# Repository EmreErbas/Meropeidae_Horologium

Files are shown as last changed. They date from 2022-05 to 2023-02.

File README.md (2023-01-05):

# Meropeidae Horologium

---
>**This project contains sub-modules. Clone the project recursively**
>
>`git clone --recurse-submodules git@github.com:EmreErbas/Meropeidae_Horologium.git`

---

## Meropeidae Horologium

It is a computer, consisting of a 16x36 resolution screen inspired by [Nixie Tubes](https://en.wikipedia.org/wiki/Nixie_tube), made of single-color LEDs selected according to the wavelength of the light emitted in the excitation of neon gas, and a WiFi-connected controller that drives it.

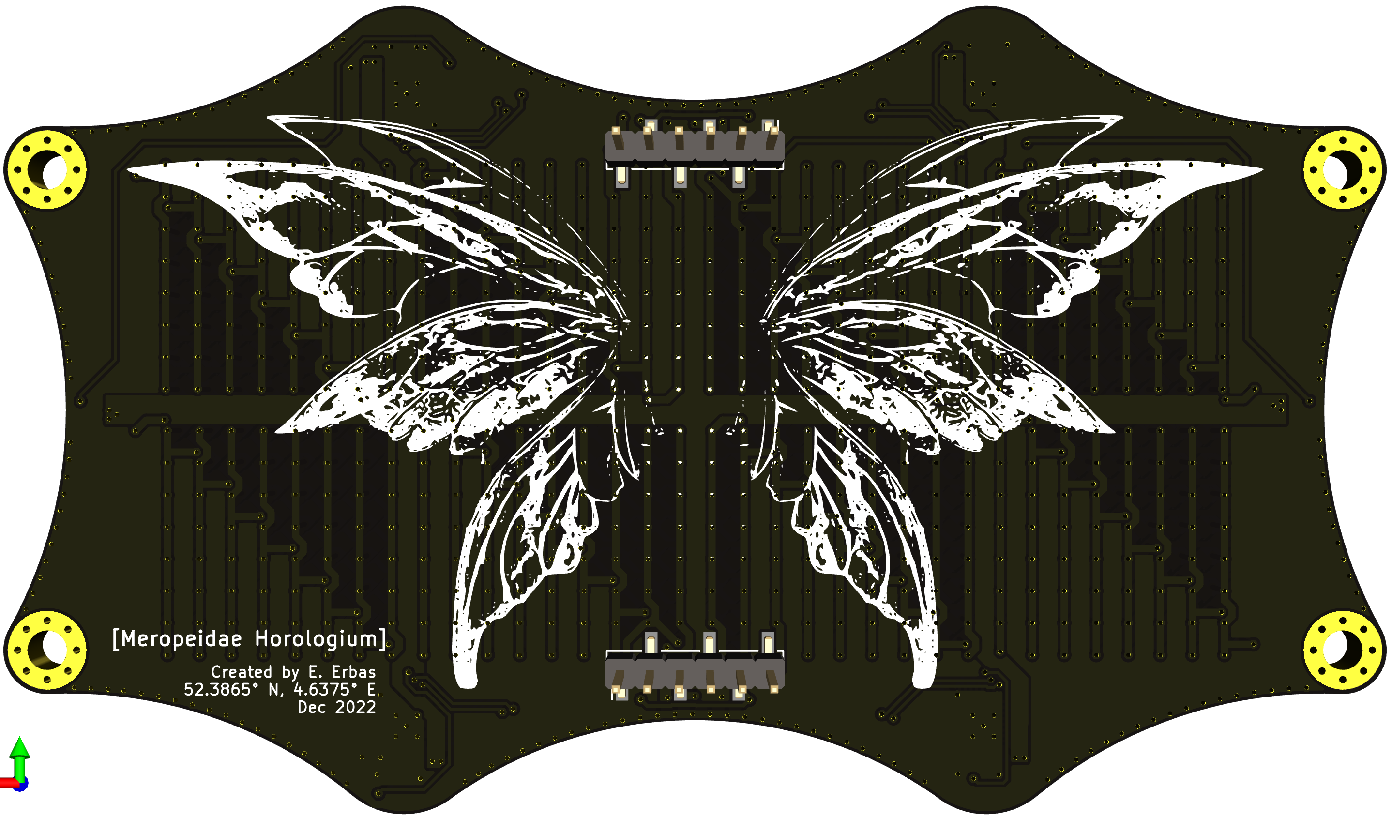
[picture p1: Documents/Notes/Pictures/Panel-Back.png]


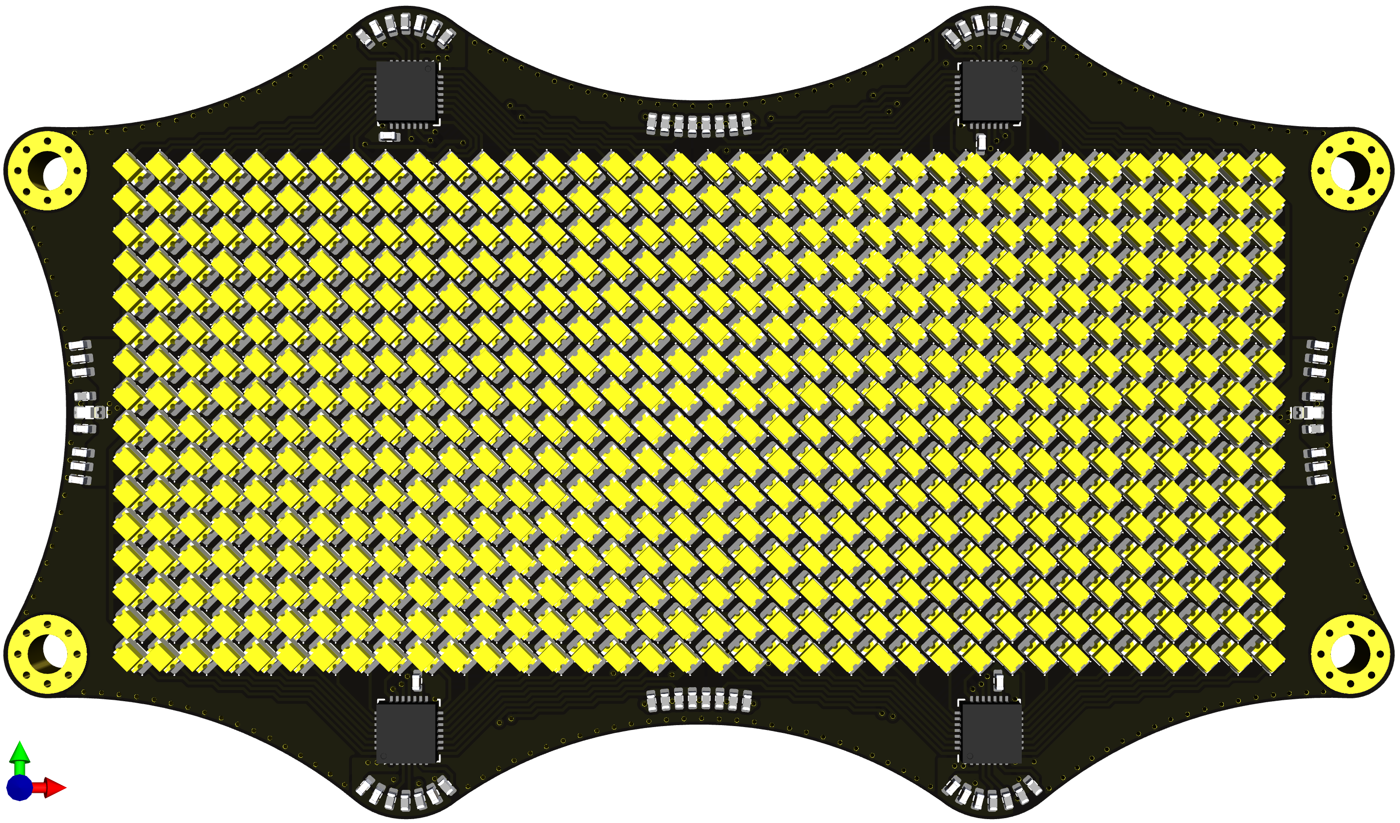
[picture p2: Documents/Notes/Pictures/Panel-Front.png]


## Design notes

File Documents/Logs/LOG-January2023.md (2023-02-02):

# Nixie-LOG-January2023 //legacy log

<pre>

<b>01-Jun-2023</b>  Started to write documents about the project

<b>02-Jun-2023</b>  Started to take technical notes. Created a file system

<b>12-Jun-2023</b>  NixiePanel PCB is arrived. ESP32-S3-Mini is arrived

<b>15-Jun-2023</b>  ESP32-S3-Mini is not really easy to use :/ I think there are some missing and/or buggy codes on the
             bootloader feature in the current library. Although I could download some simple codes, I cannot 
             download them again without entering the factory-boot-mode

<b>16-Jun-2023</b>  I saw the first light today. The PCB is working like a charm. I didn't have to change anything on the 
             hardware. But probably using two individual I2C will be a bit painful. Maybe it is wise to convert 
             the circuit for a single bus.
             Also, I need to focus on the speed of communication. I am sending all the pixels from the beginning 
             to change a single pixel. Speed is quite essential in that case. But of course, I need to find another 
             way to scan the screen.
             
<b>24-Jun-2023</b>  Every function on the panel works perfectly. Gamma correction was clearly needed and I applied it. 
             It looks like we can get very successful results somewhere between 1.6-2.0.
             I only have one issue with the system. Unfortunately, it's running extremely slow, processes with I2C. 
             Strangely, it doesn't look like it's directly connected. So I'm not entirely sure what is the source 
             of this delay. Now is the time to focus on that.
                           
<b>29-Jun-2023</b>  Interpolation and gamma correction is working like a charm. Its feeling is very flawless. First, I 
            have used more pixel data to create more smooth flow but it could not create this feeling. Then I tried 
            another method and created virtual pixels. Now, pixel positions are not integer but float. And with a 
            simgle weight calculation equation, I change the neigbor pixels' data. And it works!

</pre>

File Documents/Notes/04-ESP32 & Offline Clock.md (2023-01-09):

# ESP32 & Offline Clock

## HTML basics

`<!DOCTYPE HTML><html>` indicates that we are sending HTML  
`<head><meta name="viewport" content="width=device-width, initial-scale=1">` makes the web page responsive in any web browser
`<link rel="icon" href="data:,">` prevent requests on the favicon  
`<style>html { font-family: Helvetica; display: inline-block; margin: 0px auto; text-align: center;}` some CSS text to style the buttons and the web page appearance  
`.button { background-color: #4CAF50; border: none; color: white; padding: 16px 40px; text-decoration: none; font-size: 30px; margin: 2px; cursor: pointer;}`  
`.button2 {background-color: #555555;}</style></head>`

```html
<!DOCTYPE html>  
<html>  
<head>  
  <meta name="viewport" content="width=device-width, initial-scale=1">  
  <link rel="icon" href="data:,">  
  <style>html { font-family: Helvetica; display: inline-block; margin: 0px auto; text-align: center;}  
    .button { background-color: #4CAF50; border: none; color: white; padding: 16px 40px; 
      text-decoration: none; font-size: 30px; margin: 2px; cursor: pointer;}  
    .button2 {background-color: #555555; border: none; color: white; padding: 16px 40px; 
      text-decoration: none; font-size: 30px; margin: 2px; cursor: pointer;}  
  </style>  
  <p>  
    <a href="/26/on"><button class="button">ON</button></a>  
    <a href="/27/off"><button class="button2">OFF</button></a>  
  </p>  
</head>  
<body>  
  <h1>My First Heading</h1>  
  <p>My first paragraph.</p>  
</body>  
</html>  
```

This [webpage](https://randomnerdtutorials.com/esp32-web-server-arduino-ide/) can be useful for quick start.

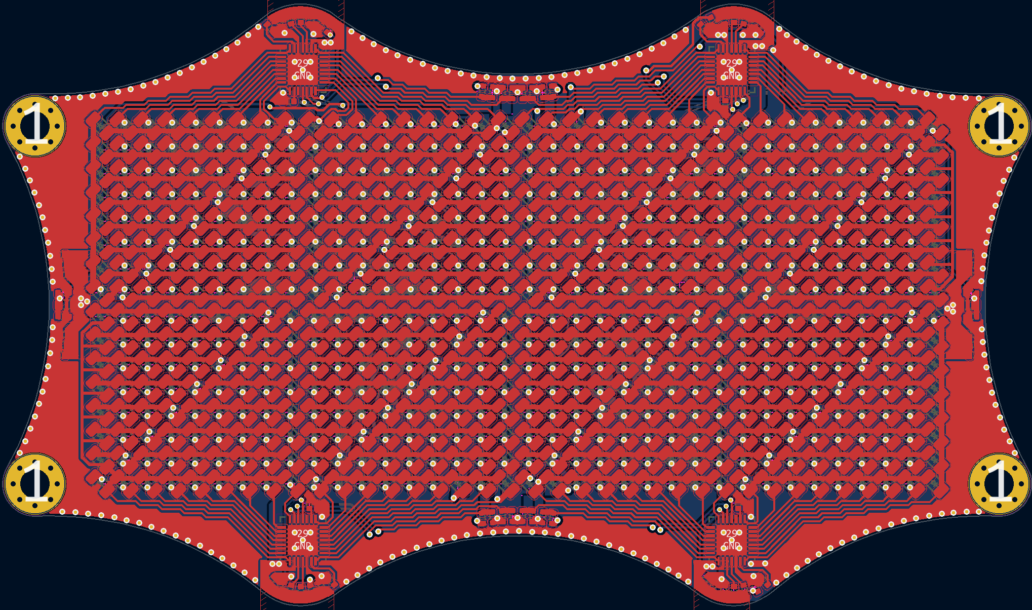
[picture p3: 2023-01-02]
Documents/Notes/Pictures/Panel-Overview.png

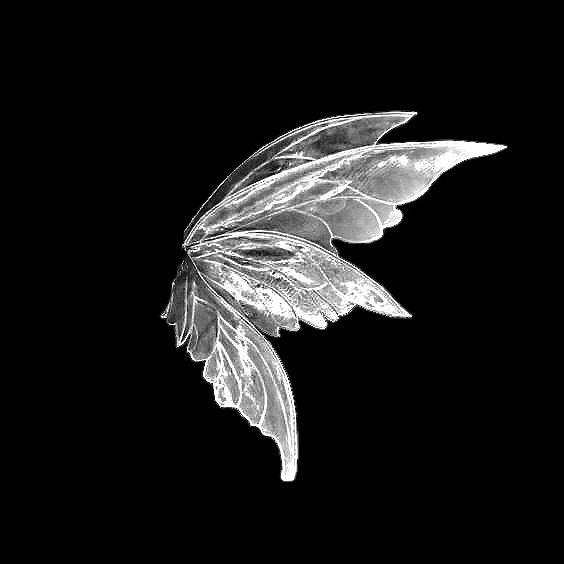
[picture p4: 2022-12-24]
Circuit Design/nixie-panel/FF75309D-6EDD-47AD-B004-FEA218AC76D5_1_201_a.jpeg

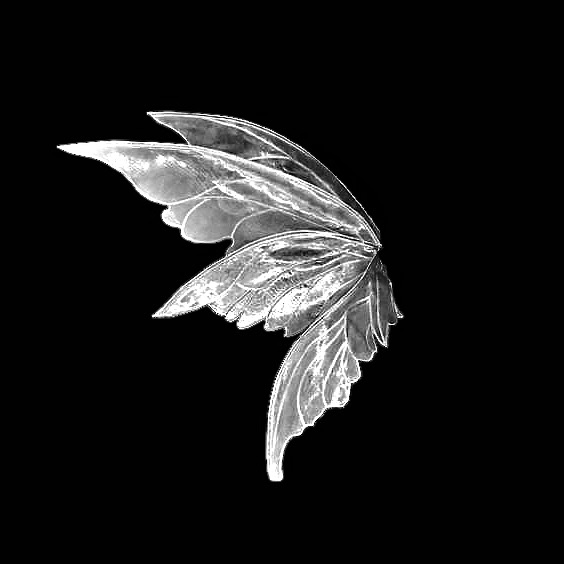
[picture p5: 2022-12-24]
Circuit Design/nixie-panel/FF75309D-6EDD-47AD-B004-FEA218AC76D5_1_201_a 2.jpeg

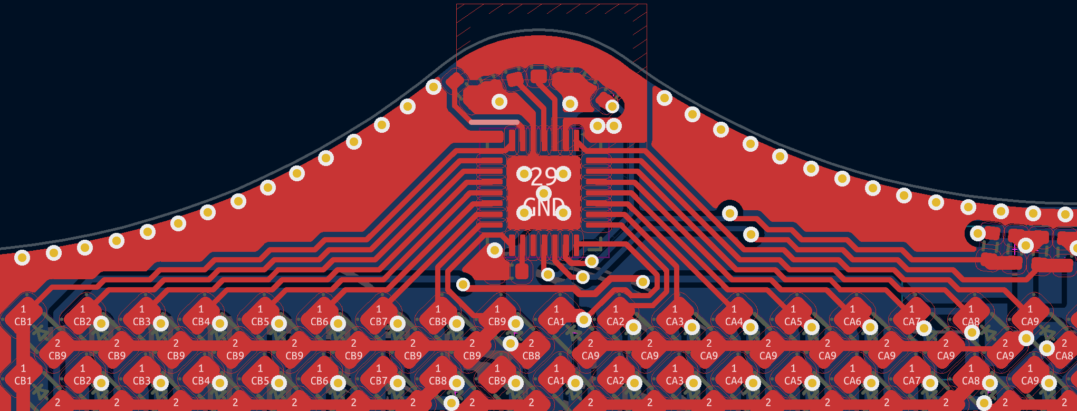
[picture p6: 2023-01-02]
Documents/Notes/Pictures/LED Driver.png

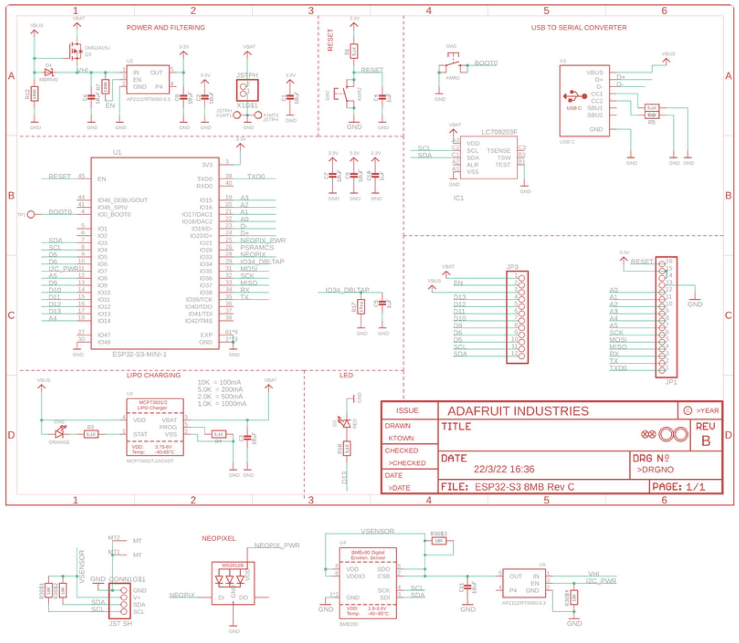
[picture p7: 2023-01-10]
Documents/Notes/Pictures/ESP32-S3-Feather-Sch.png

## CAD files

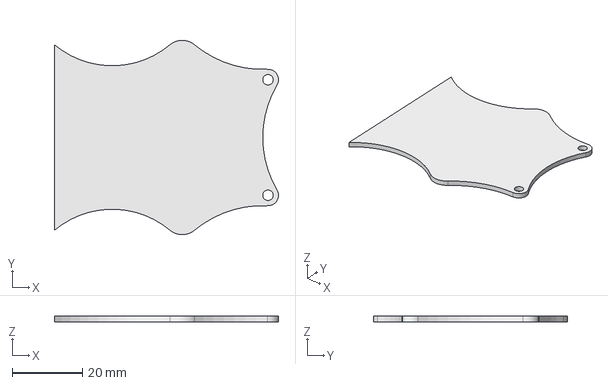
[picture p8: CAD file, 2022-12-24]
Circuit Design/nixie-panel/nixiePanelShape/nixiePanelShape.FCStd
64.0 x 55.5 x 1.60 mm

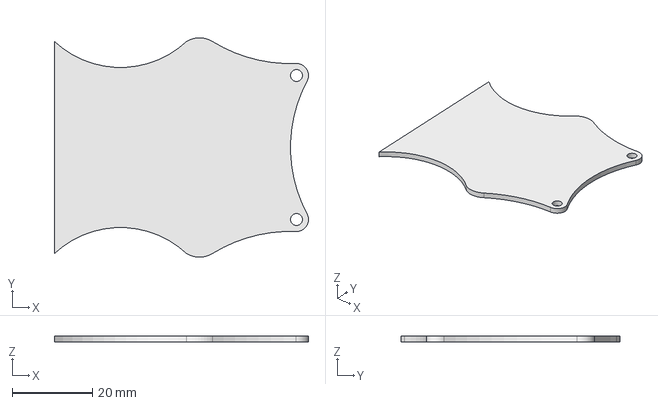
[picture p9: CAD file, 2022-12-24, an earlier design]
Circuit Design/nixie-panel/nixiePanelShape/backup/nixiePanelShape.FCStd
63.5 x 54.8 x 1.60 mm

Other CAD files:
Circuit Design/nixie-panel/nixiePanelShape/backup/nixiePanelShape.dxf
Circuit Design/nixie-panel/nixiePanelShape/nixiePanelShape.dxf

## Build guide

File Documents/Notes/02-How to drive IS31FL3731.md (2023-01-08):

# How to Drive IS31FL3731
## IS31FL3731
### GENERAL DESCRIPTION

The [IS31FL3731](https://www.lumissil.com/assets/pdf/core/IS31FL3731_DS.pdf) is a compact LED driver for 144 single LEDs. The device can be programmed via an I2C compatible interface. The IS31FL3731 offers two blocks each driving 72 LEDs with 1/9 cycle rate. The required lines to drive all 144 LEDs are reduced to 18 by using the cross-plexing feature optimizing space on the PCB. Additionally each of the 144 LEDs can be dimmed individually with 8-bit allowing 256 steps of linear dimming.

To reduce CPU usage up to 8 frames can be stored with individual time delays between frames to play small animations automatically. LED frames can be modulated with audio signal.

IS31FL3731 is available in QFN-28 (4mm × 4mm) and SSOP-28 package. It operates from 2.7V to 5.5V over the temperature range of -40°C to +85°C.

### FEATURES
* Supply voltage range: 2.7V to 5.5V 
* 400kHz I2C-compatible interface
* 144 LEDs in dot matrix
* Individual blink control
* 8 frames memory for animations
* Picture mode and animation mode
* Auto intensity breathing during the switching of different frames
* LED frames displayed can be modulated with audio signal intensity
* LED light intensity can be modulated with audio signal intensity
* QFN-28 (4mm × 4mm) and SSOP-28 package

Typical Application Circuit is:
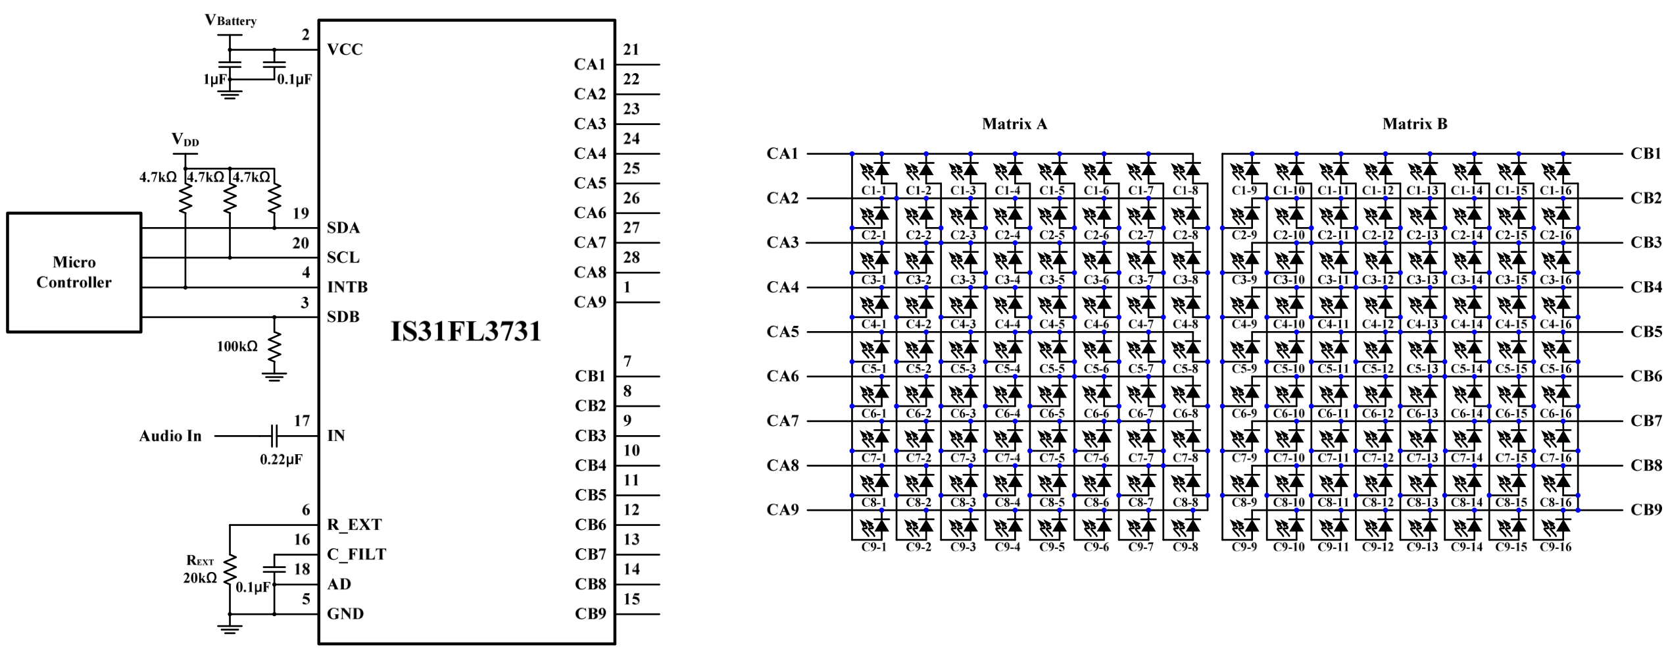
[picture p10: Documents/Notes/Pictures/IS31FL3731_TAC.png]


The circuit that the Nixie-Panel project uses is: 
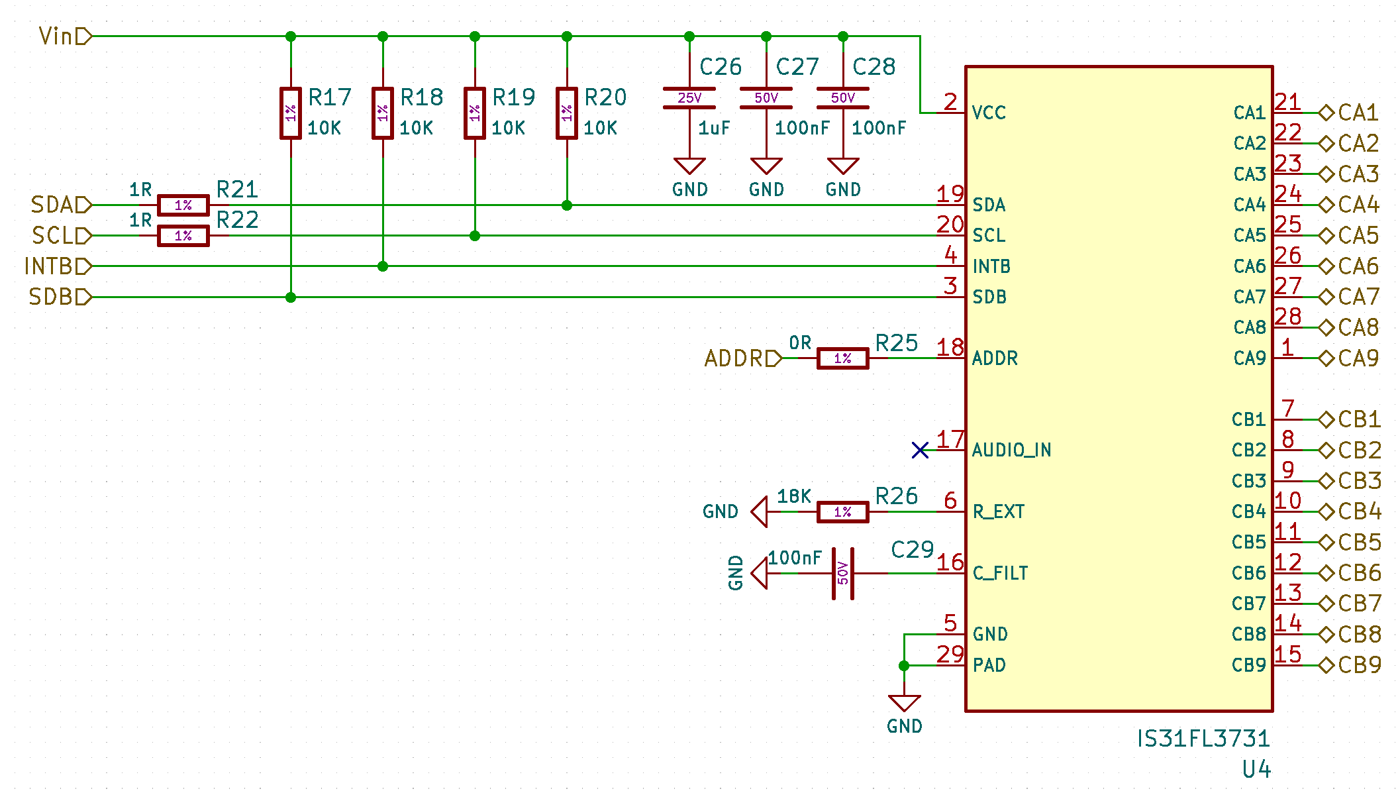
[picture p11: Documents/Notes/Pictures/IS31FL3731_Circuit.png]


under this hierarchical page:
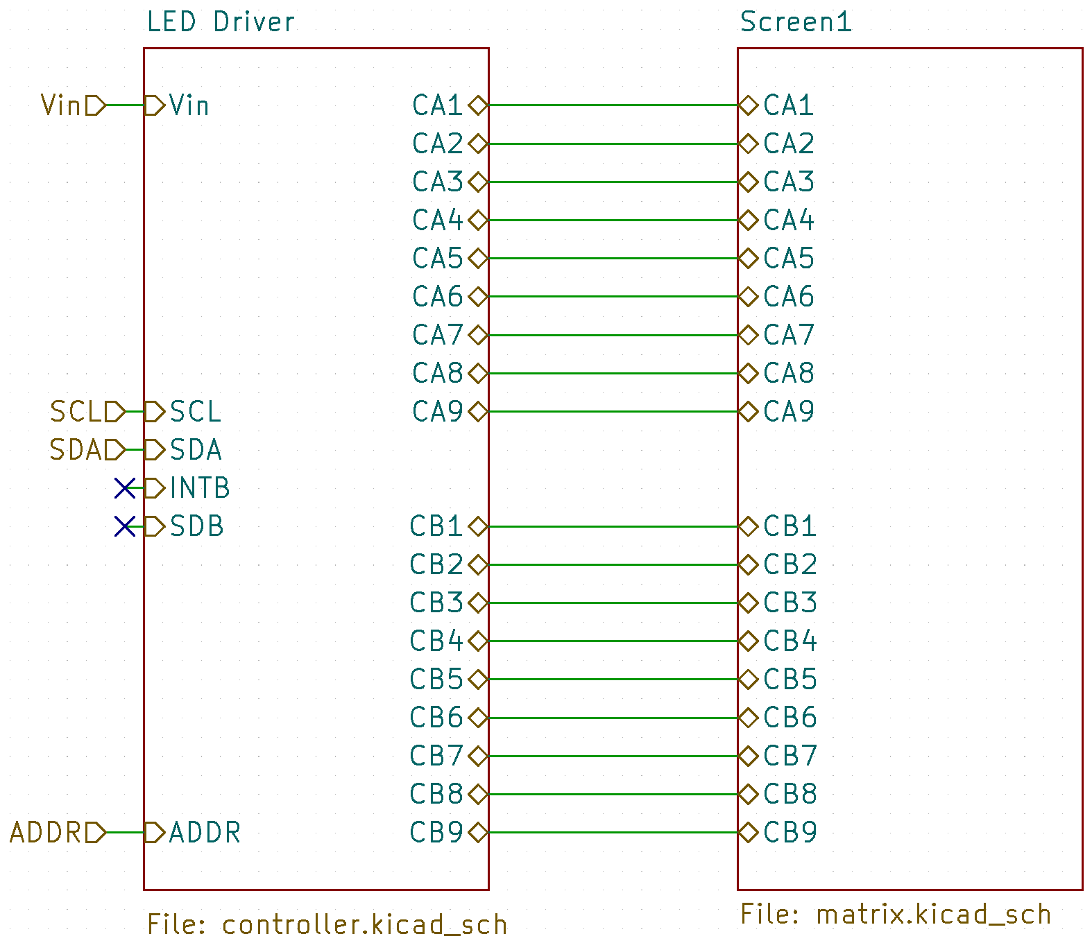
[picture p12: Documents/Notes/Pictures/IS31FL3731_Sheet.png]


## Driving the IC
Adafruit has a library for this IC. [Here](https://learn.adafruit.com/i31fl3731-16x9-charliplexed-pwm-led-driver/overview) is the link.

Open up the Arduino library manager:  
Search for the `Adafruit IS31FL3731` library and install it  
Search for the `Adafruit GFX` library and install it  

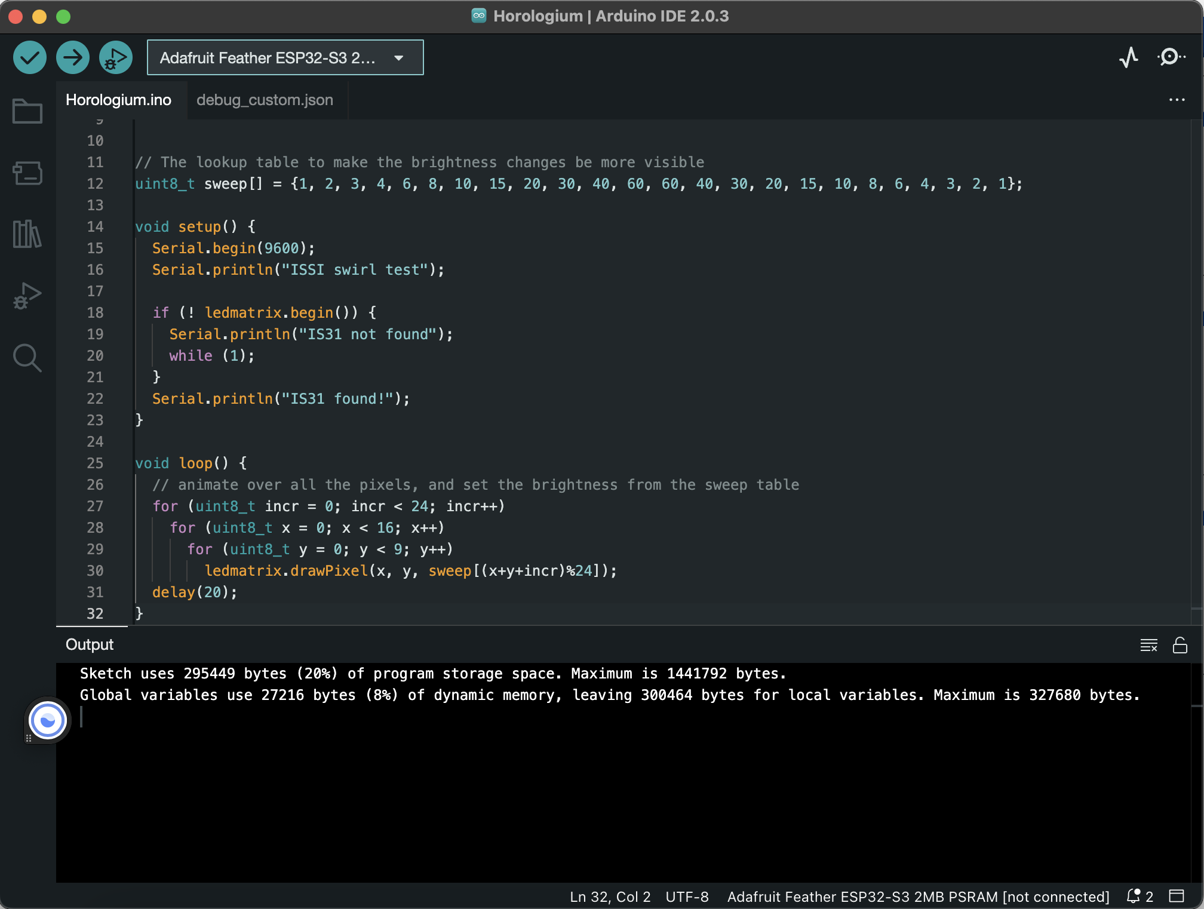
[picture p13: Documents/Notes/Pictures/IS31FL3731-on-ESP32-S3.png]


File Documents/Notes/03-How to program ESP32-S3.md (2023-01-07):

# How to Program ESP32-S3
## ESP32-S3 
<dl>
<dt>2.4 GHz WiFi + Bluetooth-LE SoC</dt>
<dt>Supporting IEEE 802.11b/g/n (2.4 GHz WiFi) and Bluetooth ® 5 (LE)</dt>
</dl>

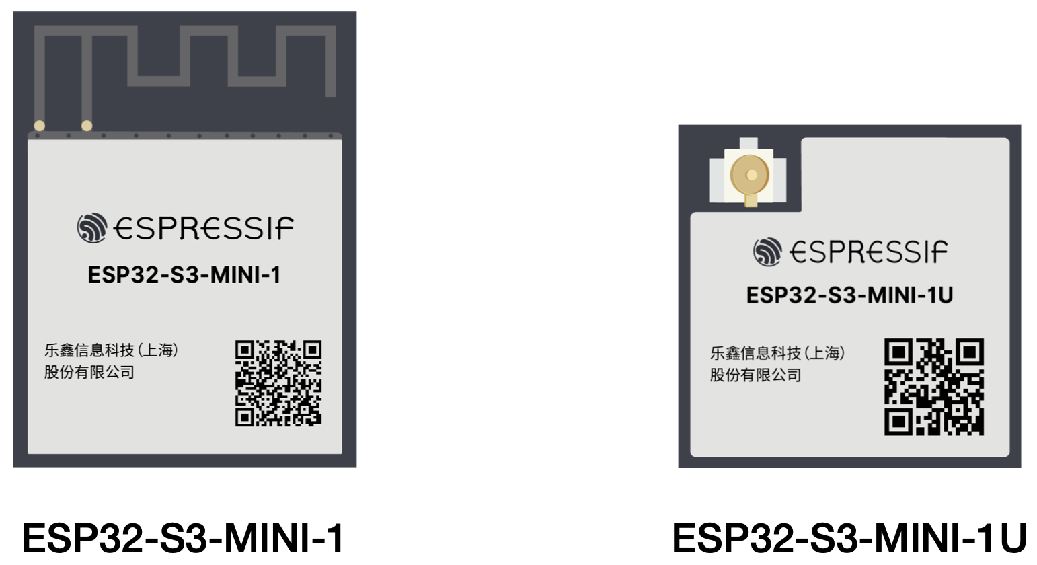
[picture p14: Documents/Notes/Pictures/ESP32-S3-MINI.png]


[ESP32-S3](https://cdn-shop.adafruit.com/product-files/5477/esp32-s3_datasheet_en.pdf) is a low-power MCU-based system-on-chip (SoC) that supports 2.4 GHz Wi-Fi and Bluetooth® Low Energy (Bluetooth LE). It consists of high-performance dual-core microprocessor (Xtensa® 32-bit LX7), a lowpower coprocessor, a Wi-Fi baseband, a Bluetooth LE baseband, RF module, and peripherals.

### FEATURES
#### WiFi
* IEEE 802.11 b/g/n-compliant
* Supports 20 MHz, 40 MHz bandwidth in 2.4 GHz band
* 1T1R mode with data rate up to 150 Mbps
* Wi-Fi Multimedia (WMM)
* TX/RX A-MPDU, TX/RX A-MSDU
* Immediate Block ACK
* Fragmentation and defragmentation
* Automatic Beacon monitoring (hardware TSF)
* 4 × virtual Wi-Fi interfaces
* Simultaneous support for Infrastructure BSS in Station, SoftAP, or Station + SoftAP modes Note that when ESP32-S3 scans in Station mode, the SoftAP channel will change along with the Station channel
* Antenna diversity
* 802.11mc FTM
* External PA is supported 
#### Bluetooth
* Bluetooth LE: Bluetooth 5, Bluetooth mesh
* High power mode (20 dBm, share the same PA with Wi-Fi)
* Speed: 125 Kbps, 500 Kbps, 1 Mbps, 2 Mbps
* Advertising extensions
* Multiple advertisement sets
* Channel selection algorithm #2
* Internal co-existence mechanism between Wi-Fi and Bluetooth to share the same antenna 
#### CPU and Memory
* Xtensa® dual-core 32-bit LX7 microprocessor, up to 240 MHz
* CoreMark® 
    score:
    - 1 core at 240 MHz: 613.86 CoreMark; 2.56 CoreMark/MHz    
    - 2 cores at 240 MHz: 1181.60 CoreMark; 4.92 CoreMark/MHz
* 128-bit data bus and SIMD commands
* 384 KB ROM
* 512 KB SRAM
* 16 KB SRAM in RTC
* SPI, Dual SPI, Quad SPI, Octal SPI, QPI and OPI interfaces that allow connection to multiple flash and external RAM
* Flash controller with cache is supported
* Flash in-Circuit Programming (ICP) is supported
#### Advanced Peripheral Interfaces
* 45 × programmable GPIOs
* Digital 
    interfaces:
    - 4 × SPI
    - 1 × LCD interface (8-bit ~16-bit parallel RGB, I8080 and MOTO6800), 
        - supporting conversion between RGB565, YUV422, YUV420 and YUV411
    - 1 × DVP 8-bit ~16-bit camera interface
    - 3 × UART
    - 2 × I2C
    - 2 × I2S
    - 1 × RMT (TX/RX)
    - 1 × pulse counter
    - LED PWM controller, up to 8 channels
    - 1 × full-speed USB OTG
    - 1 × USB Serial/JTAG controller
    - 2 × MCPWM
    - 1 × SDIO host controller with 2 slots
    - General DMA controller (GDMA), with 5 transmit channels and 5 receive channels
    - 1 × TWAI® controller, compatible with ISO 11898-1 (CAN Specification 2.0)
* Analog 
    interfaces:
    - 2 × 12-bit SAR ADCs, up to 20 channels
    - 1 × temperature sensor
    - 14 × touch sensing IOs
* Timers
    :
    - 4 × 54-bit general-purpose timers
    - 1 × 52-bit system timer
    - 3 × watchdog timers
Low Power Management
* Power Management Unit with five power modes
* Ultra-Low-Power (ULP) 
    coprocessors:
    - ULP-RISC-V coprocessor
    - ULP-FSM coprocessor
Security
* Secure boot
* Flash encryption
* 4-Kbit OTP, up to 1792 bits for users
* Cryptographic hardware 
    acceleration:
    - AES-128/256 (FIPS PUB 197)
    - Hash (FIPS PUB 180-4)
    - RSA
    - Random Number Generator (RNG)
    - HMAC
    - Digital signature

### DEVELOPMENT BOARDS

#### [Adafruit ESP32-S3 Feather](https://learn.adafruit.com/adafruit-esp32-s3-feather)


##### Features:
* ESP32-S3 Dual Core 240MHz Tensilica processor the next generation of ESP32-Sx, with native USB so it can act like a keyboard/mouse, MIDI device, disk drive, etc!
* Mini module has FCC/CE certification and comes with either 8 MByte of Flash, no PSRAM or 4MByte of Flash, and 2MB PSRAM (depending on the Feather you purchased)
* Power options - USB type C or Lipoly battery
* Built-in battery charging when powered over USB-C
* LiPoly battery monitor - LC709203 chip actively monitors your battery for voltage and state of charge / percentage reporting over I2C
* Reset and DFU (BOOT0) buttons to get into the ROM bootloader (which is a USB serial port so you don't need a separate cable!)
* Serial debug output pin (optional, for checking the hardware serial debug console)
* STEMMA QT connector for I2C devices, with switchable power, so you can go into low power mode.
* On/Charge/User LEDs + status NeoPixel with pin-controlled power for low power usage
* Low Power friendly! In deep sleep mode we can get down to ~100uA of current draw from the Lipoly connection. Quiescent current is from the power regulator, ESP32-S3 chip, and Lipoly monitor. Turn off the NeoPixel and external I2C power for the lowest quiescent current draw.

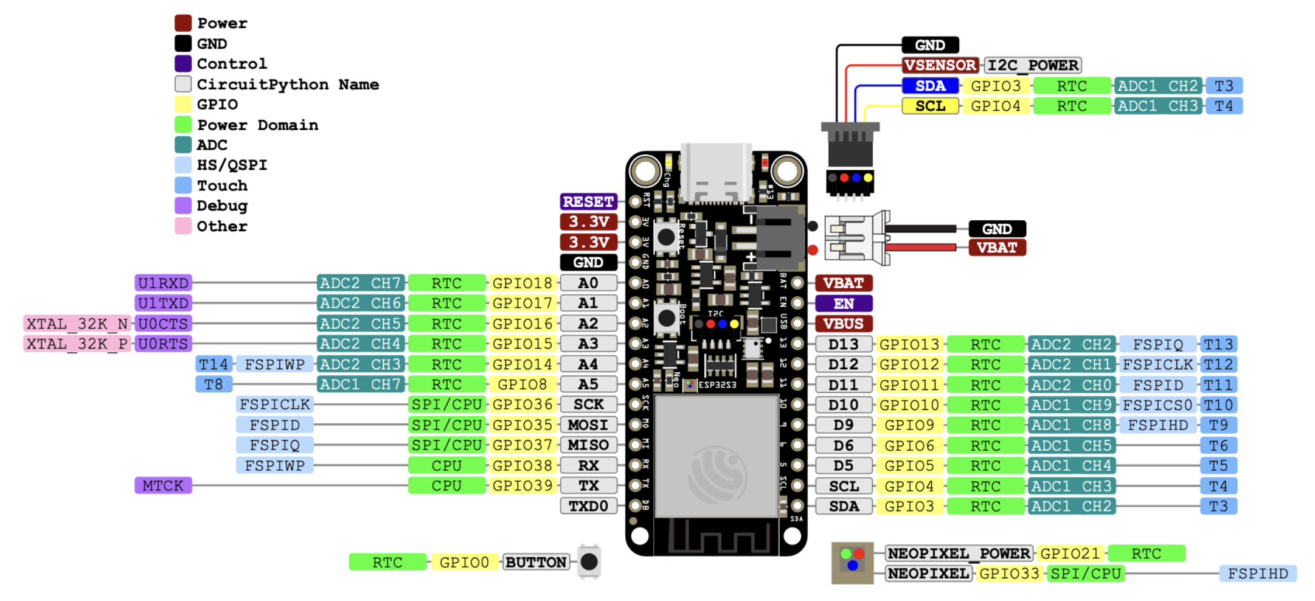
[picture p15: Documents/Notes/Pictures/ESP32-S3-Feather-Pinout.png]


### How to install the libraries

Check the [Guide](https://docs.espressif.com/projects/arduino-esp32/en/latest/installing.html#macos).

For macOS, you must istall `git` and `git-gui`.
Detailed guide is [here](https://git-scm.com/download/mac).

**[The repository of the library](https://github.com/espressif/arduino-esp32.git)**

Obviously, we need to have git installed on our PC, always.  
`$ brew install git`

The official guide recommends git-gui for installation. To follow the official guide, you need to solve several issues. I do not prefer to use the gui tool which is quite buggy on macOS. But still, you can find the solutions below.

> `$ brew install git-gui`  
> Then, you can run the gui `$ git-gui`
> 
> if python 3.9 is missing, then  
> `$ xcode-select --install`
> 
> Choose **Clone Existing Repository**  
> The source location is `https://github.com/espressif/arduino-esp32.git`  
> The target directory is `[ARDUINO_SKETCHBOOK_DIR]/hardware/espressif/esp32`, usually `/Users/[user_name]/Documents/Arduino/hardware/espressif/esp32`
> 
> **Important note:** git-gui malfunction: can not create a directory or clone one  
> to solve it, use `$ git config --global init.defaultBranch main`

Or, just run this command on terminal:  
`$ git clone --recurse-submodules https://github.com/espressif/arduino-esp32.git`

Download (get) ESP32 Board files, tools etc.  
`$ cd esp32/tools`  
`$ python3 get.py` (`python` or `python3` depends on your machine)

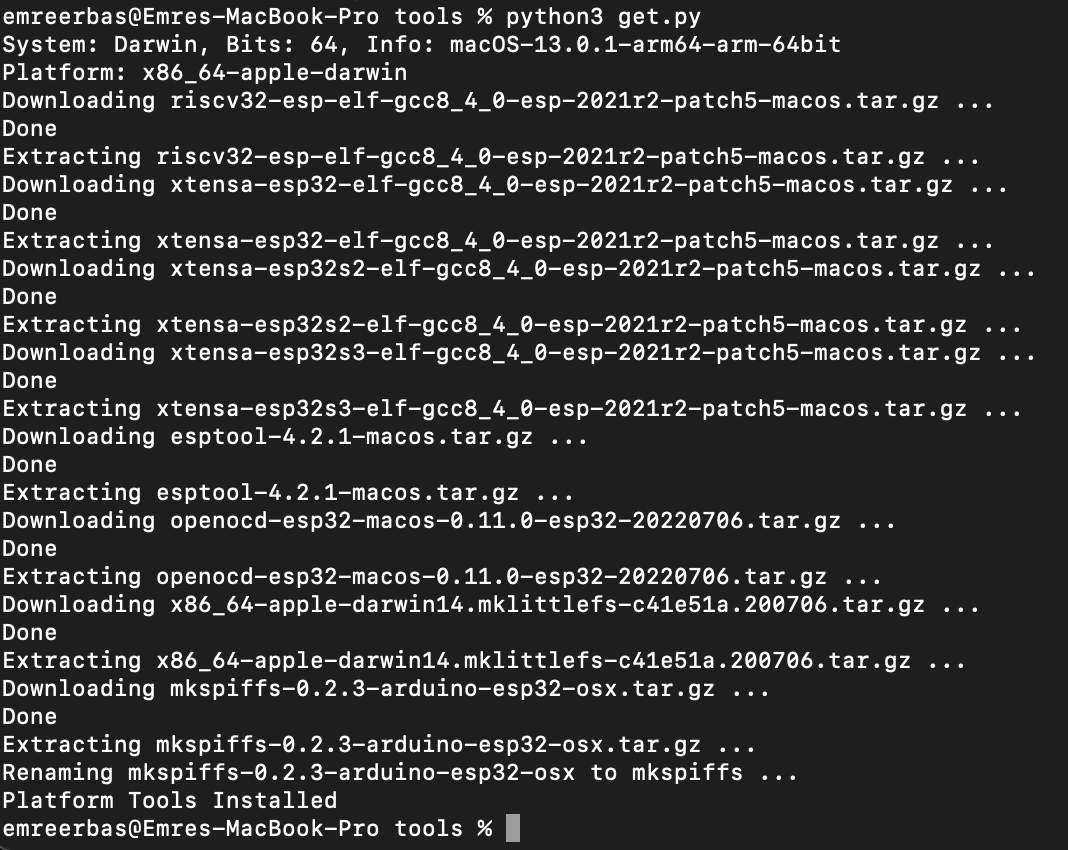
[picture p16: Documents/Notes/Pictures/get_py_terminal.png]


That is it!  
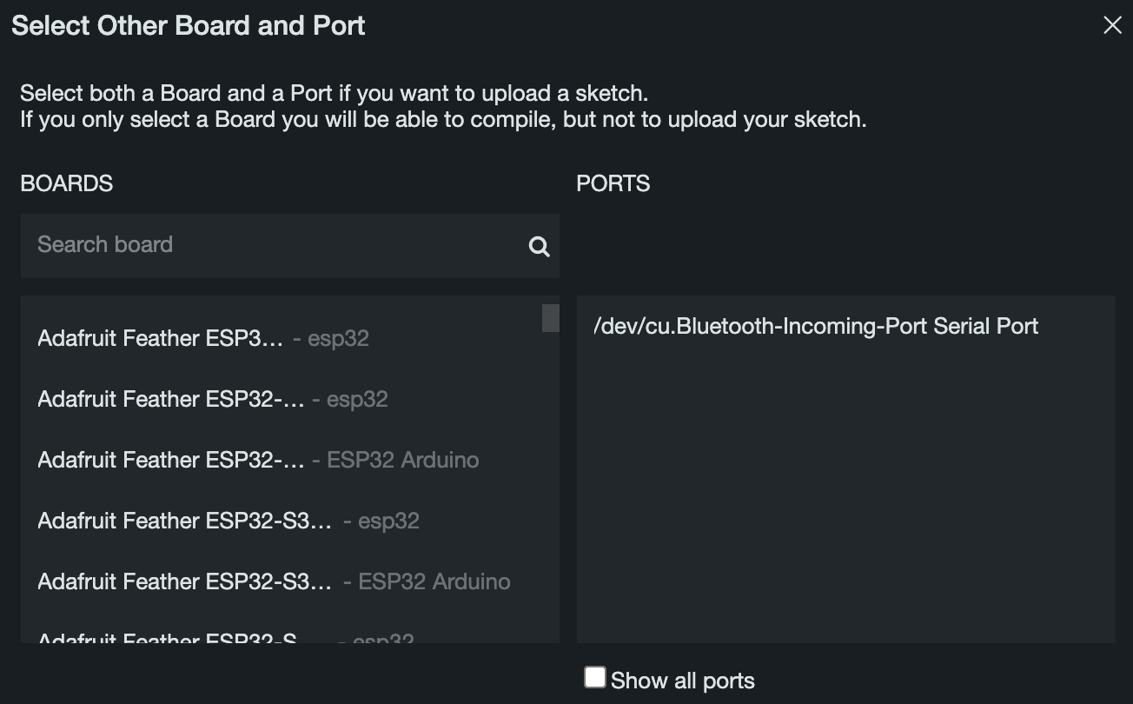
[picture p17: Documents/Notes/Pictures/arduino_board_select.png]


### Arduino IDE
Check the [Guide](https://learn.adafruit.com/adafruit-esp32-s3-feather/arduino-ide-setup)

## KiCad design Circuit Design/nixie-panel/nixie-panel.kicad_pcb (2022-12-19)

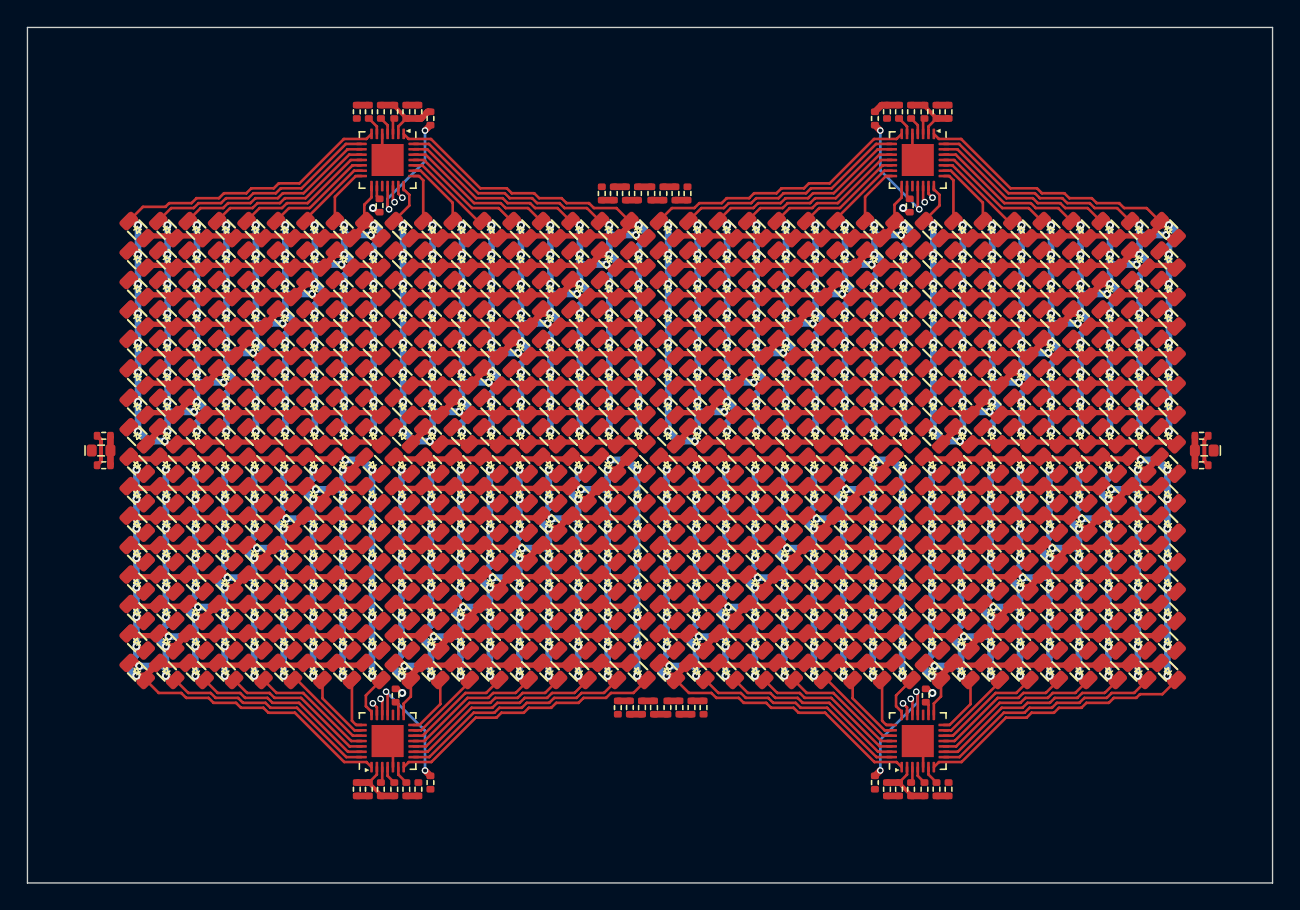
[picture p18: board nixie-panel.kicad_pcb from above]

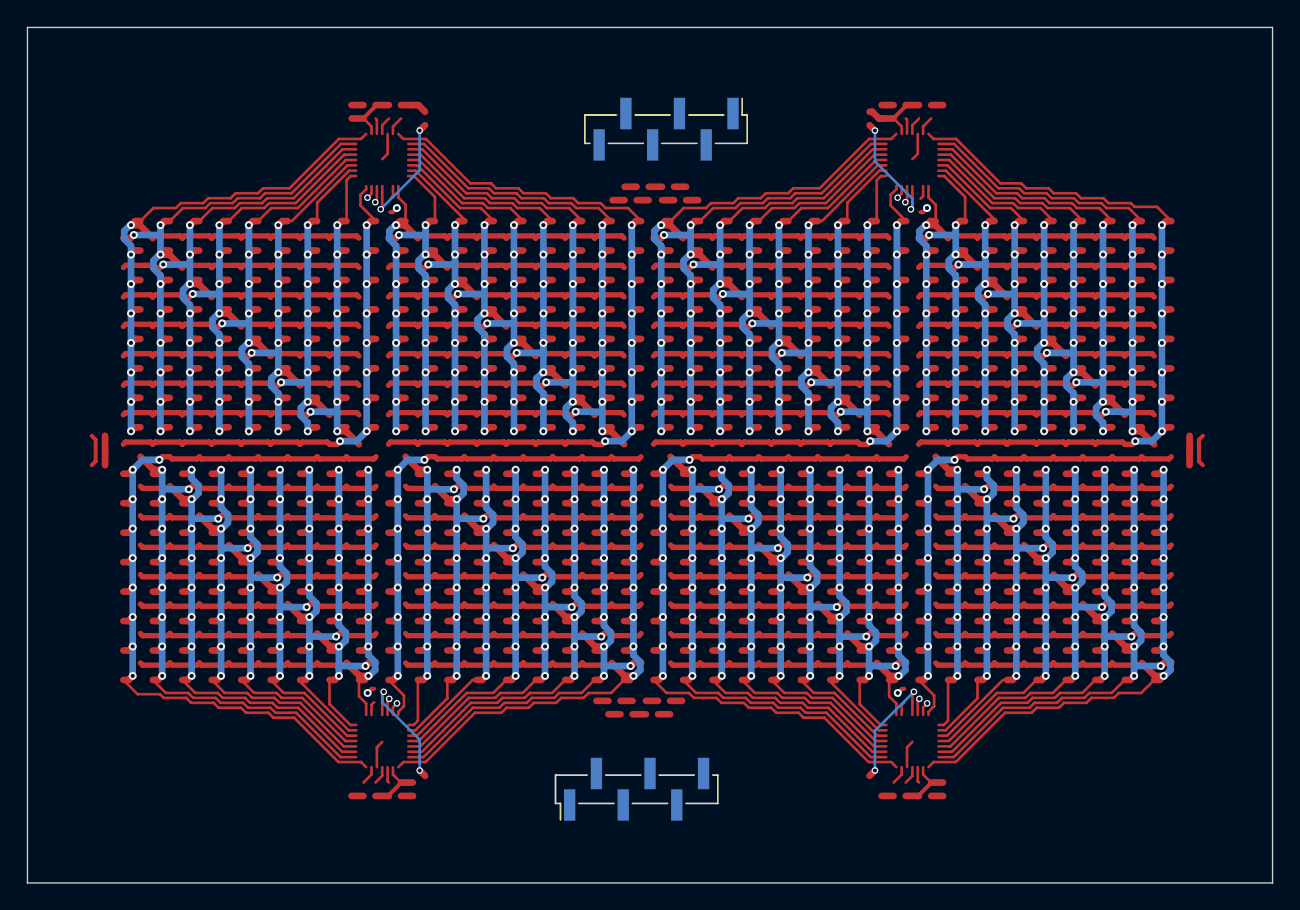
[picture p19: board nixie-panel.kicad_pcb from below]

Board: 2 copper layers, 93.0 x 63.9 mm, 636 parts (2 on the bottom side), 108 nets.

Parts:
C24, C25, C26, C30, C34, C38: 1uF; C-0402
C27, C28, C29, C31, C32, C33, C35, C36, C37, C39, C40, C41: 100nF; C-0402
D3, D4, D5, D6, D7, D8, D9, D10, D11, D12, D13, D14, D15, D16, D17, D18, D19, D20, D21, D22, D23, D24, D25, D26, D27, D28, D29, D30, D31, D32, D33, D34, D35, D36, D37, D38, D39, D40, D41, D42, D43, D44, D45, D46, D47, D48, D49, D50, D51, D52, D53, D54, D55, D56, D57, D58, D59, D60, D61, D62, D63, D64, D65, D66, D67, D68, D69, D70, D71, D72, D73, D74, D75, D76, D77, D78, D79, D80, D81, D82, D83, D84, D85, D86, D87, D88, D89, D90, D91, D92, D93, D94, D95, D96, D97, D98, D99, D100, D101, D102, D103, D104, D105, D106, D107, D108, D109, D110, D111, D112, D113, D114, D115, D116, D117, D118, D119, D120, D121, D122, D123, D124, D125, D126, D127, D128, D129, D130, D131, D132, D133, D134, D135, D136, D137, D138, D139, D140, D141, D142, D143, D144, D145, D146, D147, D148, D149, D150, D151, D152, D153, D154, D155, D156, D157, D158, D159, D160, D161, D162, D163, D164, D165, D166, D167, D168, D169, D170, D171, D172, D173, D174, D175, D176, D177, D178, D179, D180, D181, D182, D183, D184, D185, D186, D187, D188, D189, D190, D191, D192, D193, D194, D195, D196, D197, D198, D199, D200, D201, D202, D203, D204, D205, D206, D207, D208, D209, D210, D211, D212, D213, D214, D215, D216, D217, D218, D219, D220, D221, D222, D223, D224, D225, D226, D227, D228, D229, D230, D231, D232, D233, D234, D235, D236, D237, D238, D239, D240, D241, D242, D243, D244, D245, D246, D247, D248, D249, D250, D251, D252, D253, D254, D255, D256, D257, D258, D259, D260, D261, D262, D263, D264, D265, D266, D267, D268, D269, D270, D271, D272, D273, D274, D275, D276, D277, D278, D279, D280, D281, D282, D283, D284, D285, D286, D287, D288, D289, D290, D291, D292, D293, D294, D295, D296, D297, D298, D299, D300, D301, D302, D303, D304, D305, D306, D307, D308, D309, D310, D311, D312, D313, D314, D315, D316, D317, D318, D319, D320, D321, D322, D323, D324, D325, D326, D327, D328, D329, D330, D331, D332, D333, D334, D335, D336, D337, D338, D339, D340, D341, D342, D343, D344, D345, D346, D347, D348, D349, D350, D351, D352, D353, D354, D355, D356, D357, D358, D359, D360, D361, D362, D363, D364, D365, D366, D367, D368, D369, D370, D371, D372, D373, D374, D375, D376, D377, D378, D379, D380, D381, D382, D383, D384, D385, D386, D387, D388, D389, D390, D391, D392, D393, D394, D395, D396, D397, D398, D399, D400, D401, D402, D403, D404, D405, D406, D407, D408, D409, D410, D411, D412, D413, D414, D415, D416, D417, D418, D419, D420, D421, D422, D423, D424, D425, D426, D427, D428, D429, D430, D431, D432, D433, D434, D435, D436, D437, D438, D439, D440, D441, D442, D443, D444, D445, D446, D447, D448, D449, D450, D451, D452, D453, D454, D455, D456, D457, D458, D459, D460, D461, D462, D463, D464, D465, D466, D467, D468, D469, D470, D471, D472, D473, D474, D475, D476, D477, D478, D479, D480, D481, D482, D483, D484, D485, D486, D487, D488, D489, D490, D491, D492, D493, D494, D495, D496, D497, D498, D499, D500, D501, D502, D503, D504, D505, D506, D507, D508, D509, D510, D511, D512, D513, D514, D515, D516, D517, D518, D519, D520, D521, D522, D523, D524, D525, D526, D527, D528, D529, D530, D531, D532, D533, D534, D535, D536, D537, D538, D539, D540, D541, D542, D543, D544, D545, D546, D547, D548, D549, D550, D551, D552, D553, D554, D555, D556, D557, D558, D559, D560, D561, D562, D563, D564, D565, D566, D567, D568, D569, D570, D571, D572, D573, D574, D575, D576, D577, D578: LED_Y_L; LED-0805
J1, J2: Conn_01x06; PinHeader_1x06_P2.00mm_Vertical_SMD_Pin1Left
R15, R16: 2K; R-0402
R17, R18, R19, R20, R27, R28, R29, R30, R37, R38, R39, R40, R47, R48, R49, R50: 10K; R-0402
R21, R22, R31, R32, R41, R42, R51, R52: 1R; R-0402
R25, R35, R45, R55: 0R; R-0402
R26, R36, R46, R56: 18K; R-0402
S1, S2: AmbLightSns; LED-0603
U4, U5, U6, U7: IS31FL3731; QFN-28-EP

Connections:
+3V3: C26.1, C27.1, C28.1, C30.1, C31.1, C32.1, C34.1, C35.1, C36.1, C38.1, C39.1, C40.1, J1.6, J2.6, R17.1, R18.1, R19.1, R20.1, R25.1, R27.1, R28.1, R29.1, R30.1, R35.1, R37.1, R38.1, R39.1, R40.1, R47.1, R48.1, R49.1, R50.1, S1.1, S2.1, U4.2 (VCC), U5.2 (VCC), U6.2 (VCC), U7.2 (VCC)
/I2C0-SCL: J1.3, R22.1, R42.1
/I2C0-SDA: J1.4, R21.1, R41.1
/I2C1-SCL: J2.3, R32.1, R52.1
/I2C1-SDA: J2.4, R31.1, R51.1
/LightSense1: C24.1, J1.2, R15.1, S1.2
/LightSense2: C25.1, J1.5, R16.1, S2.2
/region1/LED Driver/CA1: D3.1 (K), D4.1 (K), D5.1 (K), D6.1 (K), D7.1 (K), D8.1 (K), D9.1 (K), D10.1 (K), D19.2 (A), D35.2 (A), D51.2 (A), D67.2 (A), D83.2 (A), D99.2 (A), D115.2 (A), D131.2 (A), U4.21 (CA1)
/region1/LED Driver/CA2: D3.2 (A), D19.1 (K), D20.1 (K), D21.1 (K), D22.1 (K), D23.1 (K), D24.1 (K), D25.1 (K), D26.1 (K), D36.2 (A), D52.2 (A), D68.2 (A), D84.2 (A), D100.2 (A), D116.2 (A), D132.2 (A), U4.22 (CA2)
/region1/LED Driver/CA3: D4.2 (A), D20.2 (A), D35.1 (K), D36.1 (K), D37.1 (K), D38.1 (K), D39.1 (K), D40.1 (K), D41.1 (K), D42.1 (K), D53.2 (A), D69.2 (A), D85.2 (A), D101.2 (A), D117.2 (A), D133.2 (A), U4.23 (CA3)
/region1/LED Driver/CA4: D5.2 (A), D21.2 (A), D37.2 (A), D51.1 (K), D52.1 (K), D53.1 (K), D54.1 (K), D55.1 (K), D56.1 (K), D57.1 (K), D58.1 (K), D70.2 (A), D86.2 (A), D102.2 (A), D118.2 (A), D134.2 (A), U4.24 (CA4)
/region1/LED Driver/CA5: D6.2 (A), D22.2 (A), D38.2 (A), D54.2 (A), D67.1 (K), D68.1 (K), D69.1 (K), D70.1 (K), D71.1 (K), D72.1 (K), D73.1 (K), D74.1 (K), D87.2 (A), D103.2 (A), D119.2 (A), D135.2 (A), U4.25 (CA5)
/region1/LED Driver/CA6: D7.2 (A), D23.2 (A), D39.2 (A), D55.2 (A), D71.2 (A), D83.1 (K), D84.1 (K), D85.1 (K), D86.1 (K), D87.1 (K), D88.1 (K), D89.1 (K), D90.1 (K), D104.2 (A), D120.2 (A), D136.2 (A), U4.26 (CA6)
/region1/LED Driver/CA7: D8.2 (A), D24.2 (A), D40.2 (A), D56.2 (A), D72.2 (A), D88.2 (A), D99.1 (K), D100.1 (K), D101.1 (K), D102.1 (K), D103.1 (K), D104.1 (K), D105.1 (K), D106.1 (K), D121.2 (A), D137.2 (A), U4.27 (CA7)
/region1/LED Driver/CA8: D9.2 (A), D25.2 (A), D41.2 (A), D57.2 (A), D73.2 (A), D89.2 (A), D105.2 (A), D115.1 (K), D116.1 (K), D117.1 (K), D118.1 (K), D119.1 (K), D120.1 (K), D121.1 (K), D122.1 (K), D138.2 (A), U4.28 (CA8)
/region1/LED Driver/CA9: D10.2 (A), D26.2 (A), D42.2 (A), D58.2 (A), D74.2 (A), D90.2 (A), D106.2 (A), D122.2 (A), D131.1 (K), D132.1 (K), D133.1 (K), D134.1 (K), D135.1 (K), D136.1 (K), D137.1 (K), D138.1 (K), U4.1 (CA9)
/region1/LED Driver/CB1: D11.1 (K), D12.1 (K), D13.1 (K), D14.1 (K), D15.1 (K), D16.1 (K), D17.1 (K), D18.1 (K), D27.2 (A), D43.2 (A), D59.2 (A), D75.2 (A), D91.2 (A), D107.2 (A), D123.2 (A), D139.2 (A), U4.7 (CB1)
/region1/LED Driver/CB2: D11.2 (A), D27.1 (K), D28.1 (K), D29.1 (K), D30.1 (K), D31.1 (K), D32.1 (K), D33.1 (K), D34.1 (K), D44.2 (A), D60.2 (A), D76.2 (A), D92.2 (A), D108.2 (A), D124.2 (A), D140.2 (A), U4.8 (CB2)
/region1/LED Driver/CB3: D12.2 (A), D28.2 (A), D43.1 (K), D44.1 (K), D45.1 (K), D46.1 (K), D47.1 (K), D48.1 (K), D49.1 (K), D50.1 (K), D61.2 (A), D77.2 (A), D93.2 (A), D109.2 (A), D125.2 (A), D141.2 (A), U4.9 (CB3)
/region1/LED Driver/CB4: D13.2 (A), D29.2 (A), D45.2 (A), D59.1 (K), D60.1 (K), D61.1 (K), D62.1 (K), D63.1 (K), D64.1 (K), D65.1 (K), D66.1 (K), D78.2 (A), D94.2 (A), D110.2 (A), D126.2 (A), D142.2 (A), U4.10 (CB4)
/region1/LED Driver/CB5: D14.2 (A), D30.2 (A), D46.2 (A), D62.2 (A), D75.1 (K), D76.1 (K), D77.1 (K), D78.1 (K), D79.1 (K), D80.1 (K), D81.1 (K), D82.1 (K), D95.2 (A), D111.2 (A), D127.2 (A), D143.2 (A), U4.11 (CB5)
/region1/LED Driver/CB6: D15.2 (A), D31.2 (A), D47.2 (A), D63.2 (A), D79.2 (A), D91.1 (K), D92.1 (K), D93.1 (K), D94.1 (K), D95.1 (K), D96.1 (K), D97.1 (K), D98.1 (K), D112.2 (A), D128.2 (A), D144.2 (A), U4.12 (CB6)
/region1/LED Driver/CB7: D16.2 (A), D32.2 (A), D48.2 (A), D64.2 (A), D80.2 (A), D96.2 (A), D107.1 (K), D108.1 (K), D109.1 (K), D110.1 (K), D111.1 (K), D112.1 (K), D113.1 (K), D114.1 (K), D129.2 (A), D145.2 (A), U4.13 (CB7)
/region1/LED Driver/CB8: D17.2 (A), D33.2 (A), D49.2 (A), D65.2 (A), D81.2 (A), D97.2 (A), D113.2 (A), D123.1 (K), D124.1 (K), D125.1 (K), D126.1 (K), D127.1 (K), D128.1 (K), D129.1 (K), D130.1 (K), D146.2 (A), U4.14 (CB8)
/region1/LED Driver/CB9: D18.2 (A), D34.2 (A), D50.2 (A), D66.2 (A), D82.2 (A), D98.2 (A), D114.2 (A), D130.2 (A), D139.1 (K), D140.1 (K), D141.1 (K), D142.1 (K), D143.1 (K), D144.1 (K), D145.1 (K), D146.1 (K), U4.15 (CB9)
/region1/LED Driver/INTB: R18.2, U4.4 (INTB)
/region1/LED Driver/SDB: R17.2, U4.3 (SDB)
/region2/LED Driver/CA1: D147.1 (K), D148.1 (K), D149.1 (K), D150.1 (K), D151.1 (K), D152.1 (K), D153.1 (K), D154.1 (K), D163.2 (A), D179.2 (A), D195.2 (A), D211.2 (A), D227.2 (A), D243.2 (A), D259.2 (A), D275.2 (A), U5.21 (CA1)
/region2/LED Driver/CA2: D147.2 (A), D163.1 (K), D164.1 (K), D165.1 (K), D166.1 (K), D167.1 (K), D168.1 (K), D169.1 (K), D170.1 (K), D180.2 (A), D196.2 (A), D212.2 (A), D228.2 (A), D244.2 (A), D260.2 (A), D276.2 (A), U5.22 (CA2)
/region2/LED Driver/CA3: D148.2 (A), D164.2 (A), D179.1 (K), D180.1 (K), D181.1 (K), D182.1 (K), D183.1 (K), D184.1 (K), D185.1 (K), D186.1 (K), D197.2 (A), D213.2 (A), D229.2 (A), D245.2 (A), D261.2 (A), D277.2 (A), U5.23 (CA3)
/region2/LED Driver/CA4: D149.2 (A), D165.2 (A), D181.2 (A), D195.1 (K), D196.1 (K), D197.1 (K), D198.1 (K), D199.1 (K), D200.1 (K), D201.1 (K), D202.1 (K), D214.2 (A), D230.2 (A), D246.2 (A), D262.2 (A), D278.2 (A), U5.24 (CA4)
/region2/LED Driver/CA5: D150.2 (A), D166.2 (A), D182.2 (A), D198.2 (A), D211.1 (K), D212.1 (K), D213.1 (K), D214.1 (K), D215.1 (K), D216.1 (K), D217.1 (K), D218.1 (K), D231.2 (A), D247.2 (A), D263.2 (A), D279.2 (A), U5.25 (CA5)
/region2/LED Driver/CA6: D151.2 (A), D167.2 (A), D183.2 (A), D199.2 (A), D215.2 (A), D227.1 (K), D228.1 (K), D229.1 (K), D230.1 (K), D231.1 (K), D232.1 (K), D233.1 (K), D234.1 (K), D248.2 (A), D264.2 (A), D280.2 (A), U5.26 (CA6)
/region2/LED Driver/CA7: D152.2 (A), D168.2 (A), D184.2 (A), D200.2 (A), D216.2 (A), D232.2 (A), D243.1 (K), D244.1 (K), D245.1 (K), D246.1 (K), D247.1 (K), D248.1 (K), D249.1 (K), D250.1 (K), D265.2 (A), D281.2 (A), U5.27 (CA7)
/region2/LED Driver/CA8: D153.2 (A), D169.2 (A), D185.2 (A), D201.2 (A), D217.2 (A), D233.2 (A), D249.2 (A), D259.1 (K), D260.1 (K), D261.1 (K), D262.1 (K), D263.1 (K), D264.1 (K), D265.1 (K), D266.1 (K), D282.2 (A), U5.28 (CA8)
/region2/LED Driver/CA9: D154.2 (A), D170.2 (A), D186.2 (A), D202.2 (A), D218.2 (A), D234.2 (A), D250.2 (A), D266.2 (A), D275.1 (K), D276.1 (K), D277.1 (K), D278.1 (K), D279.1 (K), D280.1 (K), D281.1 (K), D282.1 (K), U5.1 (CA9)
/region2/LED Driver/CB1: D155.1 (K), D156.1 (K), D157.1 (K), D158.1 (K), D159.1 (K), D160.1 (K), D161.1 (K), D162.1 (K), D171.2 (A), D187.2 (A), D203.2 (A), D219.2 (A), D235.2 (A), D251.2 (A), D267.2 (A), D283.2 (A), U5.7 (CB1)
/region2/LED Driver/CB2: D155.2 (A), D171.1 (K), D172.1 (K), D173.1 (K), D174.1 (K), D175.1 (K), D176.1 (K), D177.1 (K), D178.1 (K), D188.2 (A), D204.2 (A), D220.2 (A), D236.2 (A), D252.2 (A), D268.2 (A), D284.2 (A), U5.8 (CB2)
/region2/LED Driver/CB3: D156.2 (A), D172.2 (A), D187.1 (K), D188.1 (K), D189.1 (K), D190.1 (K), D191.1 (K), D192.1 (K), D193.1 (K), D194.1 (K), D205.2 (A), D221.2 (A), D237.2 (A), D253.2 (A), D269.2 (A), D285.2 (A), U5.9 (CB3)
/region2/LED Driver/CB4: D157.2 (A), D173.2 (A), D189.2 (A), D203.1 (K), D204.1 (K), D205.1 (K), D206.1 (K), D207.1 (K), D208.1 (K), D209.1 (K), D210.1 (K), D222.2 (A), D238.2 (A), D254.2 (A), D270.2 (A), D286.2 (A), U5.10 (CB4)
/region2/LED Driver/CB5: D158.2 (A), D174.2 (A), D190.2 (A), D206.2 (A), D219.1 (K), D220.1 (K), D221.1 (K), D222.1 (K), D223.1 (K), D224.1 (K), D225.1 (K), D226.1 (K), D239.2 (A), D255.2 (A), D271.2 (A), D287.2 (A), U5.11 (CB5)
/region2/LED Driver/CB6: D159.2 (A), D175.2 (A), D191.2 (A), D207.2 (A), D223.2 (A), D235.1 (K), D236.1 (K), D237.1 (K), D238.1 (K), D239.1 (K), D240.1 (K), D241.1 (K), D242.1 (K), D256.2 (A), D272.2 (A), D288.2 (A), U5.12 (CB6)
/region2/LED Driver/CB7: D160.2 (A), D176.2 (A), D192.2 (A), D208.2 (A), D224.2 (A), D240.2 (A), D251.1 (K), D252.1 (K), D253.1 (K), D254.1 (K), D255.1 (K), D256.1 (K), D257.1 (K), D258.1 (K), D273.2 (A), D289.2 (A), U5.13 (CB7)
/region2/LED Driver/CB8: D161.2 (A), D177.2 (A), D193.2 (A), D209.2 (A), D225.2 (A), D241.2 (A), D257.2 (A), D267.1 (K), D268.1 (K), D269.1 (K), D270.1 (K), D271.1 (K), D272.1 (K), D273.1 (K), D274.1 (K), D290.2 (A), U5.14 (CB8)
/region2/LED Driver/CB9: D162.2 (A), D178.2 (A), D194.2 (A), D210.2 (A), D226.2 (A), D242.2 (A), D258.2 (A), D274.2 (A), D283.1 (K), D284.1 (K), D285.1 (K), D286.1 (K), D287.1 (K), D288.1 (K), D289.1 (K), D290.1 (K), U5.15 (CB9)
/region2/LED Driver/INTB: R28.2, U5.4 (INTB)
/region2/LED Driver/SDB: R27.2, U5.3 (SDB)
/region3/LED Driver/CA1: D291.1 (K), D292.1 (K), D293.1 (K), D294.1 (K), D295.1 (K), D296.1 (K), D297.1 (K), D298.1 (K), D307.2 (A), D323.2 (A), D339.2 (A), D355.2 (A), D371.2 (A), D387.2 (A), D403.2 (A), D419.2 (A), U6.21 (CA1)
/region3/LED Driver/CA2: D291.2 (A), D307.1 (K), D308.1 (K), D309.1 (K), D310.1 (K), D311.1 (K), D312.1 (K), D313.1 (K), D314.1 (K), D324.2 (A), D340.2 (A), D356.2 (A), D372.2 (A), D388.2 (A), D404.2 (A), D420.2 (A), U6.22 (CA2)
/region3/LED Driver/CA3: D292.2 (A), D308.2 (A), D323.1 (K), D324.1 (K), D325.1 (K), D326.1 (K), D327.1 (K), D328.1 (K), D329.1 (K), D330.1 (K), D341.2 (A), D357.2 (A), D373.2 (A), D389.2 (A), D405.2 (A), D421.2 (A), U6.23 (CA3)
/region3/LED Driver/CA4: D293.2 (A), D309.2 (A), D325.2 (A), D339.1 (K), D340.1 (K), D341.1 (K), D342.1 (K), D343.1 (K), D344.1 (K), D345.1 (K), D346.1 (K), D358.2 (A), D374.2 (A), D390.2 (A), D406.2 (A), D422.2 (A), U6.24 (CA4)
/region3/LED Driver/CA5: D294.2 (A), D310.2 (A), D326.2 (A), D342.2 (A), D355.1 (K), D356.1 (K), D357.1 (K), D358.1 (K), D359.1 (K), D360.1 (K), D361.1 (K), D362.1 (K), D375.2 (A), D391.2 (A), D407.2 (A), D423.2 (A), U6.25 (CA5)
/region3/LED Driver/CA6: D295.2 (A), D311.2 (A), D327.2 (A), D343.2 (A), D359.2 (A), D371.1 (K), D372.1 (K), D373.1 (K), D374.1 (K), D375.1 (K), D376.1 (K), D377.1 (K), D378.1 (K), D392.2 (A), D408.2 (A), D424.2 (A), U6.26 (CA6)
/region3/LED Driver/CA7: D296.2 (A), D312.2 (A), D328.2 (A), D344.2 (A), D360.2 (A), D376.2 (A), D387.1 (K), D388.1 (K), D389.1 (K), D390.1 (K), D391.1 (K), D392.1 (K), D393.1 (K), D394.1 (K), D409.2 (A), D425.2 (A), U6.27 (CA7)
/region3/LED Driver/CA8: D297.2 (A), D313.2 (A), D329.2 (A), D345.2 (A), D361.2 (A), D377.2 (A), D393.2 (A), D403.1 (K), D404.1 (K), D405.1 (K), D406.1 (K), D407.1 (K), D408.1 (K), D409.1 (K), D410.1 (K), D426.2 (A), U6.28 (CA8)
/region3/LED Driver/CA9: D298.2 (A), D314.2 (A), D330.2 (A), D346.2 (A), D362.2 (A), D378.2 (A), D394.2 (A), D410.2 (A), D419.1 (K), D420.1 (K), D421.1 (K), D422.1 (K), D423.1 (K), D424.1 (K), D425.1 (K), D426.1 (K), U6.1 (CA9)
/region3/LED Driver/CB1: D299.1 (K), D300.1 (K), D301.1 (K), D302.1 (K), D303.1 (K), D304.1 (K), D305.1 (K), D306.1 (K), D315.2 (A), D331.2 (A), D347.2 (A), D363.2 (A), D379.2 (A), D395.2 (A), D411.2 (A), D427.2 (A), U6.7 (CB1)
/region3/LED Driver/CB2: D299.2 (A), D315.1 (K), D316.1 (K), D317.1 (K), D318.1 (K), D319.1 (K), D320.1 (K), D321.1 (K), D322.1 (K), D332.2 (A), D348.2 (A), D364.2 (A), D380.2 (A), D396.2 (A), D412.2 (A), D428.2 (A), U6.8 (CB2)
/region3/LED Driver/CB3: D300.2 (A), D316.2 (A), D331.1 (K), D332.1 (K), D333.1 (K), D334.1 (K), D335.1 (K), D336.1 (K), D337.1 (K), D338.1 (K), D349.2 (A), D365.2 (A), D381.2 (A), D397.2 (A), D413.2 (A), D429.2 (A), U6.9 (CB3)
/region3/LED Driver/CB4: D301.2 (A), D317.2 (A), D333.2 (A), D347.1 (K), D348.1 (K), D349.1 (K), D350.1 (K), D351.1 (K), D352.1 (K), D353.1 (K), D354.1 (K), D366.2 (A), D382.2 (A), D398.2 (A), D414.2 (A), D430.2 (A), U6.10 (CB4)
/region3/LED Driver/CB5: D302.2 (A), D318.2 (A), D334.2 (A), D350.2 (A), D363.1 (K), D364.1 (K), D365.1 (K), D366.1 (K), D367.1 (K), D368.1 (K), D369.1 (K), D370.1 (K), D383.2 (A), D399.2 (A), D415.2 (A), D431.2 (A), U6.11 (CB5)
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

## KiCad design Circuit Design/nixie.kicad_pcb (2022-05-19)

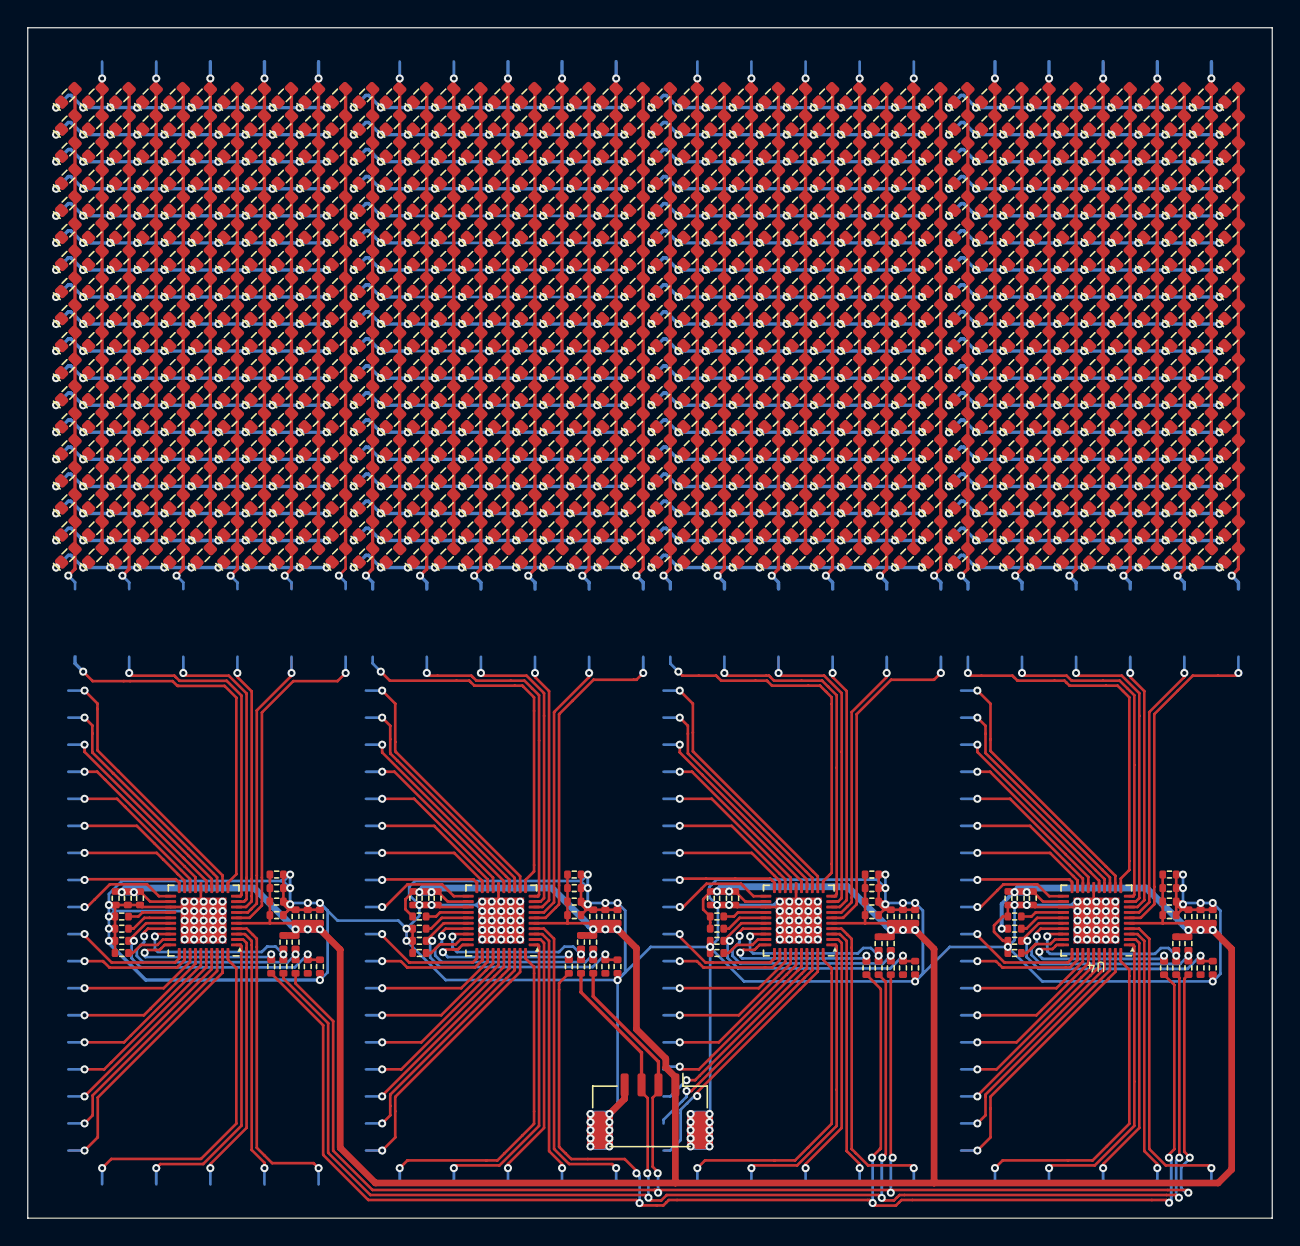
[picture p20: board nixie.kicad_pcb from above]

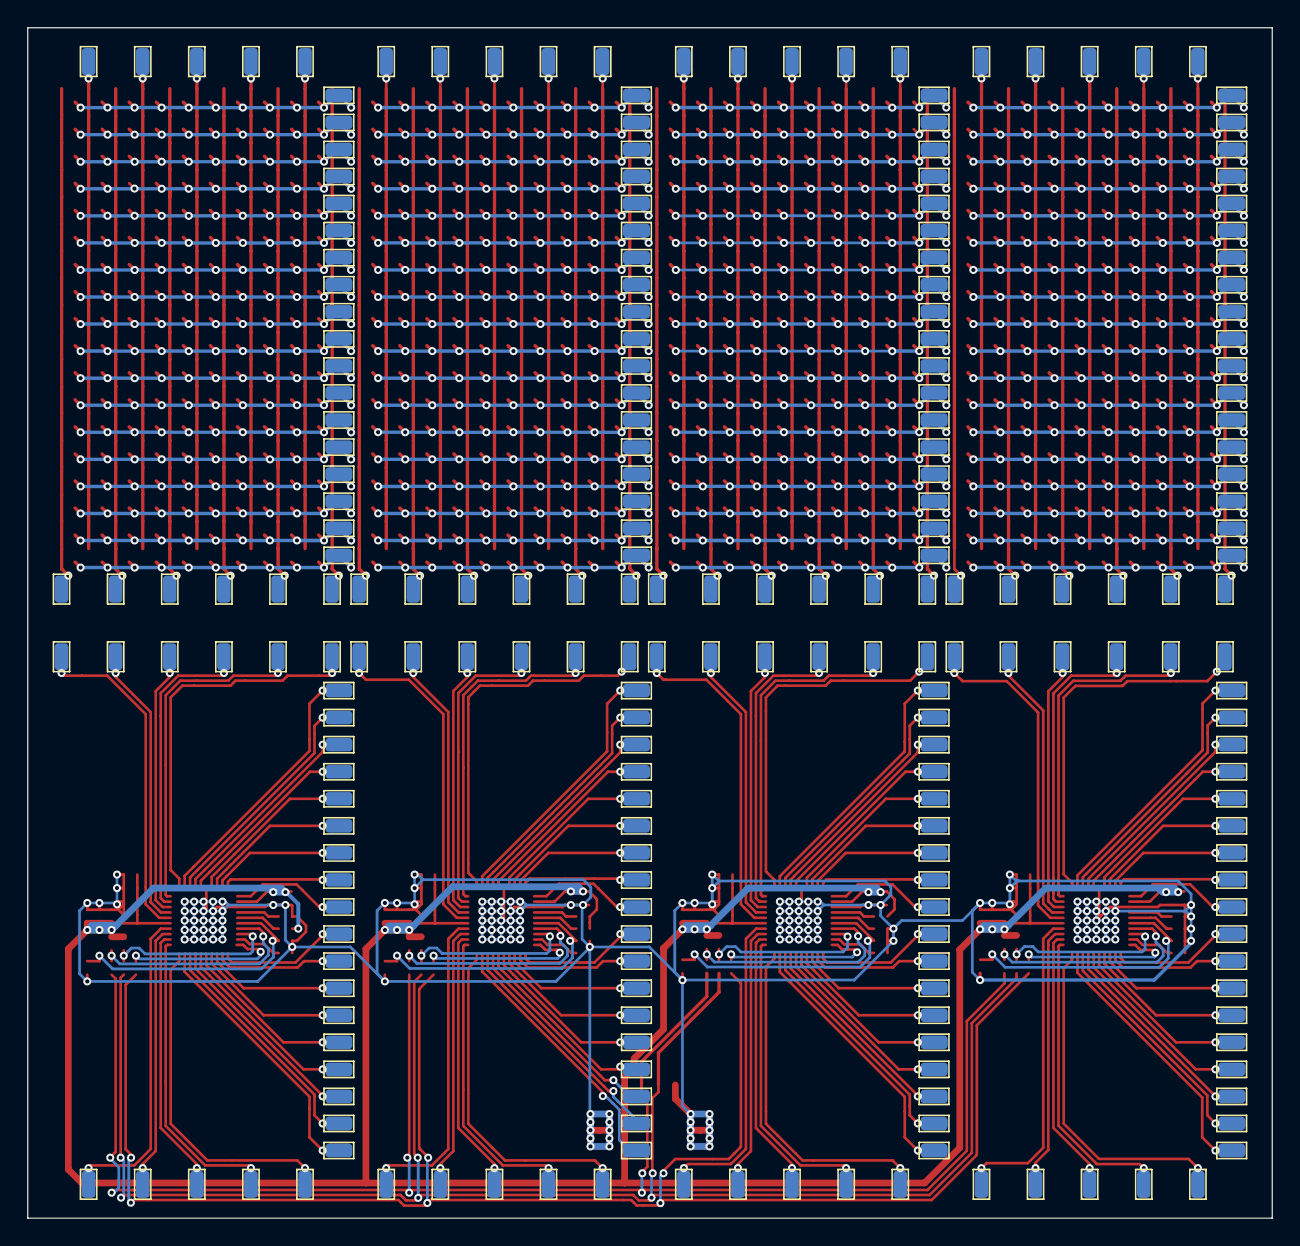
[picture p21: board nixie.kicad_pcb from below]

Board: 2 copper layers, 92.0 x 88.0 mm, 1113 parts (232 on the bottom side), 265 nets.

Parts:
C1, C2, C3, C4, C5, C6, C7, C8, C9, C10, C11, C12, C13, C16, C20, C23, C27, C30, C34, C35, C36, C37, C38, C41: 1uF; C-0402
C14, C15, C17, C18, C19, C21, C22, C24, C25, C26, C28, C29, C31, C32, C33, C39, C40, C42, C43, C44: 100nF; C-0402
CP1, CP2, CP3, CP4, CP5, CP6, CP7, CP8, CP9, CP10, CP11, CP12, CP13, CP14, CP15, CP16, CP17, CP18, CP19, CP20, CP21, CP22, CP23, CP24, CP25, CP26, CP27, CP28, CP29, CP30, CP31, CP32, CP33, CP34, CP35, CP36, CP37, CP38, CP39, CP40, CP41, CP42, CP43, CP44, CP45, CP46, CP47, CP48, CP49, CP50, CP51, CP52, CP53, CP54, CP55, CP56, CP57, CP58, CP59, CP60, CP61, CP62, CP63, CP64, CP65, CP66, CP67, CP68, CP69, CP70, CP71, CP72, CP73, CP74, CP75, CP76, CP77, CP78, CP79, CP80, CP81, CP82, CP83, CP84, CP85, CP86, CP87, CP88, CP89, CP90, CP91, CP92, CP93, CP94, CP95, CP96, CP97, CP98, CP99, CP100, CP101, CP102, CP103, CP104, CP105, CP106, CP107, CP108, CP109, CP110, CP111, CP112, CP113, CP114, CP115, CP116, CP117, CP118, CP119, CP120, CP121, CP122, CP123, CP124, CP125, CP126, CP127, CP128, CP129, CP130, CP131, CP132, CP133, CP134, CP135, CP136, CP137, CP138, CP139, CP140, CP141, CP142, CP143, CP144, CP145, CP146, CP147, CP148, CP149, CP150, CP151, CP152, CP153, CP154, CP155, CP156, CP157, CP158, CP159, CP160, CP161, CP162, CP163, CP164, CP165, CP166, CP167, CP168, CP169, CP170, CP171, CP172, CP173, CP174, CP175, CP176, CP177, CP178, CP179, CP180, CP181, CP182, CP183, CP184, CP185, CP186, CP187, CP188, CP189, CP190, CP191, CP192, CP193, CP194, CP195, CP196, CP197, CP198, CP199, CP200, CP201, CP202, CP203, CP204, CP205, CP206, CP207, CP208, CP209, CP210, CP211, CP212, CP213, CP214, CP215, CP216, CP217, CP218, CP219, CP220, CP221, CP222, CP223, CP224, CP225, CP226, CP227, CP228, CP229, CP230, CP231, CP232: SolderPad; SolderPt_1x2mm
D1, D2, D3, D4, D5, D6, D7, D8, D9, D10, D11, D12, D13, D14, D15, D16, D17, D18, D19, D20, D21, D22, D23, D24, D25, D26, D27, D28, D29, D30, D31, D32, D33, D34, D35, D36, D37, D38, D39, D40, D41, D42, D43, D44, D45, D46, D47, D48, D49, D50, D51, D52, D53, D54, D55, D56, D57, D58, D59, D60, D61, D62, D63, D64, D65, D66, D67, D68, D69, D70, D71, D72, D73, D74, D75, D76, D77, D78, D79, D80, D81, D82, D83, D84, D85, D86, D87, D88, D89, D90, D91, D92, D93, D94, D95, D96, D97, D98, D99, D100, D101, D102, D103, D104, D105, D106, D107, D108, D109, D110, D111, D112, D113, D114, D115, D116, D117, D118, D119, D120, D121, D122, D123, D124, D125, D126, D127, D128, D129, D130, D131, D132, D133, D134, D135, D136, D137, D138, D139, D140, D141, D142, D143, D144, D145, D146, D147, D148, D149, D150, D151, D152, D153, D154, D155, D156, D157, D158, D159, D160, D161, D162, D163, D164, D165, D166, D167, D168, D169, D170, D171, D172, D173, D174, D175, D176, D177, D178, D179, D180, D181, D182, D183, D184, D185, D186, D187, D188, D189, D190, D191, D192, D193, D194, D195, D196, D197, D198, D199, D200, D201, D202, D203, D204, D205, D206, D207, D208, D209, D210, D211, D212, D213, D214, D215, D216, D217, D218, D219, D220, D221, D222, D223, D224, D225, D226, D227, D228, D229, D230, D231, D232, D233, D234, D235, D236, D237, D238, D239, D240, D241, D242, D243, D244, D245, D246, D247, D248, D249, D250, D251, D252, D253, D254, D255, D256, D257, D258, D259, D260, D261, D262, D263, D264, D265, D266, D267, D268, D269, D270, D271, D272, D273, D274, D275, D276, D277, D278, D279, D280, D281, D282, D283, D284, D285, D286, D287, D288, D289, D290, D291, D292, D293, D294, D295, D296, D297, D298, D299, D300, D301, D302, D303, D304, D305, D306, D307, D308, D309, D310, D311, D312, D313, D314, D315, D316, D317, D318, D319, D320, D321, D322, D323, D324, D325, D326, D327, D328, D329, D330, D331, D332, D333, D334, D335, D336, D337, D338, D339, D340, D341, D342, D343, D344, D345, D346, D347, D348, D349, D350, D351, D352, D353, D354, D355, D356, D357, D358, D359, D360, D361, D362, D363, D364, D365, D366, D367, D368, D369, D370, D371, D372, D373, D374, D375, D376, D377, D378, D379, D380, D381, D382, D383, D384, D385, D386, D387, D388, D389, D390, D391, D392, D393, D394, D395, D396, D397, D398, D399, D400, D401, D402, D403, D404, D405, D406, D407, D408, D409, D410, D411, D412, D413, D414, D415, D416, D417, D418, D419, D420, D421, D422, D423, D424, D425, D426, D427, D428, D429, D430, D431, D432, D433, D434, D435, D436, D437, D438, D439, D440, D441, D442, D443, D444, D445, D446, D447, D448, D449, D450, D451, D452, D453, D454, D455, D456, D457, D458, D459, D460, D461, D462, D463, D464, D465, D466, D467, D468, D469, D470, D471, D472, D473, D474, D475, D476, D477, D478, D479, D480, D481, D482, D483, D484, D485, D486, D487, D488, D489, D490, D491, D492, D493, D494, D495, D496, D497, D498, D499, D500, D501, D502, D503, D504, D505, D506, D507, D508, D509, D510, D511, D512, D513, D514, D515, D516, D517, D518, D519, D520, D521, D522, D523, D524, D525, D526, D527, D528, D529, D530, D531, D532, D533, D534, D535, D536, D537, D538, D539, D540, D541, D542, D543, D544, D545, D546, D547, D548, D549, D550, D551, D552, D553, D554, D555, D556, D557, D558, D559, D560, D561, D562, D563, D564, D565, D566, D567, D568, D569, D570, D571, D572, D573, D574, D575, D576, D577, D578, D579, D580, D581, D582, D583, D584, D585, D586, D587, D588, D589, D590, D591, D592, D593, D594, D595, D596, D597, D598, D599, D600, D601, D602, D603, D604, D605, D606, D607, D608, D609, D610, D611, D612, D613, D614, D615, D616, D617, D618, D619, D620, D621, D622, D623, D624, D625, D626, D627, D628, D629, D630, D631, D632, D633, D634, D635, D636, D637, D638, D639, D640, D641, D642, D643, D644, D645, D646, D647, D648, D649, D650, D651, D652, D653, D654, D655, D656, D657, D658, D659, D660, D661, D662, D663, D664, D665, D666, D667, D668, D669, D670, D671, D672, D673, D674, D675, D676, D677, D678, D679, D680, D681, D682, D683, D684, D685, D686, D687, D688, D689, D690, D691, D692, D693, D694, D695, D696, D697, D698, D699, D700, D701, D702, D703, D704, D705, D706, D707, D708, D709, D710, D711, D712, D713, D714, D715, D716, D717, D718, D719, D720, D721, D722, D723, D724, D725, D726, D727, D728, D729, D730, D731, D732, D733, D734, D735, D736, D737, D738, D739, D740, D741, D742, D743, D744, D745, D746, D747, D748, D749, D750, D751, D752, D753, D754, D755, D756, D757, D758, D759, D760, D761, D762, D763, D764, D765, D766, D767, D768, D769, D770, D771, D772, D773, D774, D775, D776, D777, D778, D779, D780, D781, D782, D783, D784, D785, D786, D787, D788, D789, D790, D791, D792: LED_A; LED-0603
J1: BM04B-GHS-TBT
R1, R2, R11, R12, R21, R22, R31, R32: 10K; R-0402
R3, R4, R5, R13, R14, R15, R23, R24, R25, R33, R34, R35: 22R; R-0402
R6, R16, R26, R36: 100K; R-0402
R7, R9, R10, R17, R19, R20, R27, R29, R30, R37, R39, R40: 0R; R-0402
R8, R18, R28, R38: 18K; R-0402
U1, U2, U3, U4: IS31FL3743A; QFN-40-EP

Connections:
+3V3: C1.1, C2.1, C3.1, C4.1, C5.1, C6.1, C7.1, C8.1, C9.1, C10.1, C11.1, C12.1, C13.1, C14.1, C15.1, C16.1, C17.1, C18.1, C20.1, C21.1, C22.1, C23.1, C24.1, C25.1, C27.1, C28.1, C29.1, C30.1, C31.1, C32.1, C34.1, C35.1, C36.1, C37.1, C38.1, C39.1, C40.1, C41.1, C42.1, C43.1, J1.1, R1.1, R2.1, R11.1, R12.1, R19.1, R21.1, R22.1, R29.1, R30.1, R31.1, R32.1, R40.1, U1.5 (PVCC), U1.22 (VCC), U2.5 (PVCC), U2.22 (VCC), U3.5 (PVCC), U3.22 (VCC), U4.5 (PVCC), U4.22 (VCC)
/LED Driver1/CS1: CP171.1, U2.39 (CS1)
/LED Driver1/CS2: CP165.1, U2.38 (CS2)
/LED Driver1/CS3: CP159.1, U2.37 (CS3)
/LED Driver1/CS4: CP153.1, U2.36 (CS4)
/LED Driver1/CS5: CP147.1, U2.35 (CS5)
/LED Driver1/CS6: CP141.1, U2.34 (CS6)
/LED Driver1/CS7: CP135.1, U2.33 (CS7)
/LED Driver1/CS8: CP129.1, U2.32 (CS8)
/LED Driver1/CS9: CP123.1, U2.31 (CS9)
/LED Driver1/CS10: CP117.1, U2.21 (CS10)
/LED Driver1/CS11: CP111.1, U2.20 (CS11)
/LED Driver1/CS12: CP105.1, U2.19 (CS12)
/LED Driver1/CS13: CP99.1, U2.18 (CS13)
/LED Driver1/CS14: CP93.1, U2.17 (CS14)
/LED Driver1/CS15: CP87.1, U2.15 (CS15)
/LED Driver1/CS16: CP81.1, U2.14 (CS16)
/LED Driver1/CS17: CP75.1, U2.13 (CS17)
/LED Driver1/CS18: CP69.1, U2.12 (CS18)
/LED Driver1/SW1: CP3.1, U2.6 (SW1)
/LED Driver1/SW2: CP9.1, U2.4 (SW2)
/LED Driver1/SW3: CP15.1, U2.7 (SW3)
/LED Driver1/SW4: CP21.1, U2.3 (SW4)
/LED Driver1/SW5: CP27.1, U2.8 (SW5)
/LED Driver1/SW6: CP33.1, U2.2 (SW6)
/LED Driver1/SW7: CP39.1, U2.9 (SW7)
/LED Driver1/SW8: CP45.1, U2.1 (SW8)
/LED Driver1/SW9: CP51.1, U2.10 (SW9)
/LED Driver1/SW10: CP57.1, U2.40 (SW10)
/LED Driver1/SW11: CP63.1, U2.11 (SW11)
/LED Driver2/CS1: CP173.1, U3.39 (CS1)
/LED Driver2/CS2: CP167.1, U3.38 (CS2)
/LED Driver2/CS3: CP161.1, U3.37 (CS3)
/LED Driver2/CS4: CP155.1, U3.36 (CS4)
/LED Driver2/CS5: CP149.1, U3.35 (CS5)
/LED Driver2/CS6: CP143.1, U3.34 (CS6)
/LED Driver2/CS7: CP137.1, U3.33 (CS7)
/LED Driver2/CS8: CP131.1, U3.32 (CS8)
/LED Driver2/CS9: CP125.1, U3.31 (CS9)
/LED Driver2/CS10: CP119.1, U3.21 (CS10)
/LED Driver2/CS11: CP113.1, U3.20 (CS11)
/LED Driver2/CS12: CP107.1, U3.19 (CS12)
/LED Driver2/CS13: CP101.1, U3.18 (CS13)
/LED Driver2/CS14: CP95.1, U3.17 (CS14)
/LED Driver2/CS15: CP89.1, U3.15 (CS15)
/LED Driver2/CS16: CP83.1, U3.14 (CS16)
/LED Driver2/CS17: CP77.1, U3.13 (CS17)
/LED Driver2/CS18: CP71.1, U3.12 (CS18)
/LED Driver2/SW1: CP5.1, U3.6 (SW1)
/LED Driver2/SW2: CP11.1, U3.4 (SW2)
/LED Driver2/SW3: CP17.1, U3.7 (SW3)
/LED Driver2/SW4: CP23.1, U3.3 (SW4)
/LED Driver2/SW5: CP29.1, U3.8 (SW5)
/LED Driver2/SW6: CP35.1, U3.2 (SW6)
/LED Driver2/SW7: CP41.1, U3.9 (SW7)
/LED Driver2/SW8: CP47.1, U3.1 (SW8)
/LED Driver2/SW9: CP53.1, U3.10 (SW9)
/LED Driver2/SW10: CP59.1, U3.40 (SW10)
/LED Driver2/SW11: CP65.1, U3.11 (SW11)
/LED Driver3/CS1: CP231.1, U4.39 (CS1)
/LED Driver3/CS2: CP229.1, U4.38 (CS2)
/LED Driver3/CS3: CP227.1, U4.37 (CS3)
/LED Driver3/CS4: CP225.1, U4.36 (CS4)
/LED Driver3/CS5: CP223.1, U4.35 (CS5)
/LED Driver3/CS6: CP221.1, U4.34 (CS6)
/LED Driver3/CS7: CP219.1, U4.33 (CS7)
/LED Driver3/CS8: CP217.1, U4.32 (CS8)
/LED Driver3/CS9: CP215.1, U4.31 (CS9)
/LED Driver3/CS10: CP213.1, U4.21 (CS10)
/LED Driver3/CS11: CP211.1, U4.20 (CS11)
/LED Driver3/CS12: CP209.1, U4.19 (CS12)
/LED Driver3/CS13: CP207.1, U4.18 (CS13)
/LED Driver3/CS14: CP205.1, U4.17 (CS14)
/LED Driver3/CS15: CP203.1, U4.15 (CS15)
/LED Driver3/CS16: CP201.1, U4.14 (CS16)
/LED Driver3/CS17: CP199.1, U4.13 (CS17)
/LED Driver3/CS18: CP197.1, U4.12 (CS18)
/LED Driver3/SW1: CP175.1, U4.6 (SW1)
/LED Driver3/SW2: CP177.1, U4.4 (SW2)
/LED Driver3/SW3: CP179.1, U4.7 (SW3)
/LED Driver3/SW4: CP181.1, U4.3 (SW4)
/LED Driver3/SW5: CP183.1, U4.8 (SW5)
/LED Driver3/SW6: CP185.1, U4.2 (SW6)
/LED Driver3/SW7: CP187.1, U4.9 (SW7)
/LED Driver3/SW8: CP189.1, U4.1 (SW8)
/LED Driver3/SW9: CP191.1, U4.10 (SW9)
/LED Driver3/SW10: CP193.1, U4.40 (SW10)
/LED Driver3/SW11: CP195.1, U4.11 (SW11)
/LED Driver/CS1: CP169.1, U1.39 (CS1)
/LED Driver/CS2: CP163.1, U1.38 (CS2)
/LED Driver/CS3: CP157.1, U1.37 (CS3)
/LED Driver/CS4: CP151.1, U1.36 (CS4)
/LED Driver/CS5: CP145.1, U1.35 (CS5)
/LED Driver/CS6: CP139.1, U1.34 (CS6)
/LED Driver/CS7: CP133.1, U1.33 (CS7)
/LED Driver/CS8: CP127.1, U1.32 (CS8)
/LED Driver/CS9: CP121.1, U1.31 (CS9)
/LED Driver/CS10: CP115.1, U1.21 (CS10)
/LED Driver/CS11: CP109.1, U1.20 (CS11)
/LED Driver/CS12: CP103.1, U1.19 (CS12)
/LED Driver/CS13: CP97.1, U1.18 (CS13)
/LED Driver/CS14: CP91.1, U1.17 (CS14)
/LED Driver/CS15: CP85.1, U1.15 (CS15)
/LED Driver/CS16: CP79.1, U1.14 (CS16)
/LED Driver/CS17: CP73.1, U1.13 (CS17)
/LED Driver/CS18: CP67.1, U1.12 (CS18)
/LED Driver/SW1: CP1.1, U1.6 (SW1)
/LED Driver/SW2: CP7.1, U1.4 (SW2)
/LED Driver/SW3: CP13.1, U1.7 (SW3)
/LED Driver/SW4: CP19.1, U1.3 (SW4)
/LED Driver/SW5: CP25.1, U1.8 (SW5)
/LED Driver/SW6: CP31.1, U1.2 (SW6)
/LED Driver/SW7: CP37.1, U1.9 (SW7)
/LED Driver/SW8: CP43.1, U1.1 (SW8)
/LED Driver/SW9: CP49.1, U1.10 (SW9)
/LED Driver/SW10: CP55.1, U1.40 (SW10)
/LED Driver/SW11: CP61.1, U1.11 (SW11)
/SCL: J1.2, R4.1, R14.1, R24.1, R34.1
/SDA: J1.3, R3.1, R13.1, R23.1, R33.1
/SYNC: R7.1, R17.1, R27.1, R37.1
/Screen1/CS1: CP172.1, D199.1 (K), D217.1 (K), D235.1 (K), D253.1 (K), D271.1 (K), D289.1 (K), D307.1 (K), D325.1 (K), D343.1 (K), D361.1 (K), D379.1 (K)
/Screen1/CS2: CP166.1, D200.1 (K), D218.1 (K), D236.1 (K), D254.1 (K), D272.1 (K), D290.1 (K), D308.1 (K), D326.1 (K), D344.1 (K), D362.1 (K), D380.1 (K)
/Screen1/CS3: CP160.1, D201.1 (K), D219.1 (K), D237.1 (K), D255.1 (K), D273.1 (K), D291.1 (K), D309.1 (K), D327.1 (K), D345.1 (K), D363.1 (K), D381.1 (K)
/Screen1/CS4: CP154.1, D202.1 (K), D220.1 (K), D238.1 (K), D256.1 (K), D274.1 (K), D292.1 (K), D310.1 (K), D328.1 (K), D346.1 (K), D364.1 (K), D382.1 (K)
/Screen1/CS5: CP148.1, D203.1 (K), D221.1 (K), D239.1 (K), D257.1 (K), D275.1 (K), D293.1 (K), D311.1 (K), D329.1 (K), D347.1 (K), D365.1 (K), D383.1 (K)
/Screen1/CS6: CP142.1, D204.1 (K), D222.1 (K), D240.1 (K), D258.1 (K), D276.1 (K), D294.1 (K), D312.1 (K), D330.1 (K), D348.1 (K), D366.1 (K), D384.1 (K)
/Screen1/CS7: CP136.1, D205.1 (K), D223.1 (K), D241.1 (K), D259.1 (K), D277.1 (K), D295.1 (K), D313.1 (K), D331.1 (K), D349.1 (K), D367.1 (K), D385.1 (K)
/Screen1/CS8: CP130.1, D206.1 (K), D224.1 (K), D242.1 (K), D260.1 (K), D278.1 (K), D296.1 (K), D314.1 (K), D332.1 (K), D350.1 (K), D368.1 (K), D386.1 (K)
/Screen1/CS9: CP124.1, D207.1 (K), D225.1 (K), D243.1 (K), D261.1 (K), D279.1 (K), D297.1 (K), D315.1 (K), D333.1 (K), D351.1 (K), D369.1 (K), D387.1 (K)
/Screen1/CS10: CP118.1, D208.1 (K), D226.1 (K), D244.1 (K), D262.1 (K), D280.1 (K), D298.1 (K), D316.1 (K), D334.1 (K), D352.1 (K), D370.1 (K), D388.1 (K)
/Screen1/CS11: CP112.1, D209.1 (K), D227.1 (K), D245.1 (K), D263.1 (K), D281.1 (K), D299.1 (K), D317.1 (K), D335.1 (K), D353.1 (K), D371.1 (K), D389.1 (K)
/Screen1/CS12: CP106.1, D210.1 (K), D228.1 (K), D246.1 (K), D264.1 (K), D282.1 (K), D300.1 (K), D318.1 (K), D336.1 (K), D354.1 (K), D372.1 (K), D390.1 (K)
/Screen1/CS13: CP100.1, D211.1 (K), D229.1 (K), D247.1 (K), D265.1 (K), D283.1 (K), D301.1 (K), D319.1 (K), D337.1 (K), D355.1 (K), D373.1 (K), D391.1 (K)
/Screen1/CS14: CP94.1, D212.1 (K), D230.1 (K), D248.1 (K), D266.1 (K), D284.1 (K), D302.1 (K), D320.1 (K), D338.1 (K), D356.1 (K), D374.1 (K), D392.1 (K)
/Screen1/CS15: CP88.1, D213.1 (K), D231.1 (K), D249.1 (K), D267.1 (K), D285.1 (K), D303.1 (K), D321.1 (K), D339.1 (K), D357.1 (K), D375.1 (K), D393.1 (K)
/Screen1/CS16: CP82.1, D214.1 (K), D232.1 (K), D250.1 (K), D268.1 (K), D286.1 (K), D304.1 (K), D322.1 (K), D340.1 (K), D358.1 (K), D376.1 (K), D394.1 (K)
/Screen1/CS17: CP76.1, D215.1 (K), D233.1 (K), D251.1 (K), D269.1 (K), D287.1 (K), D305.1 (K), D323.1 (K), D341.1 (K), D359.1 (K), D377.1 (K), D395.1 (K)
/Screen1/CS18: CP70.1, D216.1 (K), D234.1 (K), D252.1 (K), D270.1 (K), D288.1 (K), D306.1 (K), D324.1 (K), D342.1 (K), D360.1 (K), D378.1 (K), D396.1 (K)
/Screen1/SW1: CP64.1, D199.2 (A), D200.2 (A), D201.2 (A), D202.2 (A), D203.2 (A), D204.2 (A), D205.2 (A), D206.2 (A), D207.2 (A), D208.2 (A), D209.2 (A), D210.2 (A), D211.2 (A), D212.2 (A), D213.2 (A), D214.2 (A), D215.2 (A), D216.2 (A)
/Screen1/SW2: CP58.1, D217.2 (A), D218.2 (A), D219.2 (A), D220.2 (A), D221.2 (A), D222.2 (A), D223.2 (A), D224.2 (A), D225.2 (A), D226.2 (A), D227.2 (A), D228.2 (A), D229.2 (A), D230.2 (A), D231.2 (A), D232.2 (A), D233.2 (A), D234.2 (A)
/Screen1/SW3: CP52.1, D235.2 (A), D236.2 (A), D237.2 (A), D238.2 (A), D239.2 (A), D240.2 (A), D241.2 (A), D242.2 (A), D243.2 (A), D244.2 (A), D245.2 (A), D246.2 (A), D247.2 (A), D248.2 (A), D249.2 (A), D250.2 (A), D251.2 (A), D252.2 (A)
/Screen1/SW4: CP46.1, D253.2 (A), D254.2 (A), D255.2 (A), D256.2 (A), D257.2 (A), D258.2 (A), D259.2 (A), D260.2 (A), D261.2 (A), D262.2 (A), D263.2 (A), D264.2 (A), D265.2 (A), D266.2 (A), D267.2 (A), D268.2 (A), D269.2 (A), D270.2 (A)
/Screen1/SW5: CP40.1, D271.2 (A), D272.2 (A), D273.2 (A), D274.2 (A), D275.2 (A), D276.2 (A), D277.2 (A), D278.2 (A), D279.2 (A), D280.2 (A), D281.2 (A), D282.2 (A), D283.2 (A), D284.2 (A), D285.2 (A), D286.2 (A), D287.2 (A), D288.2 (A)
/Screen1/SW6: CP34.1, D289.2 (A), D290.2 (A), D291.2 (A), D292.2 (A), D293.2 (A), D294.2 (A), D295.2 (A), D296.2 (A), D297.2 (A), D298.2 (A), D299.2 (A), D300.2 (A), D301.2 (A), D302.2 (A), D303.2 (A), D304.2 (A), D305.2 (A), D306.2 (A)
/Screen1/SW7: CP28.1, D307.2 (A), D308.2 (A), D309.2 (A), D310.2 (A), D311.2 (A), D312.2 (A), D313.2 (A), D314.2 (A), D315.2 (A), D316.2 (A), D317.2 (A), D318.2 (A), D319.2 (A), D320.2 (A), D321.2 (A), D322.2 (A), D323.2 (A), D324.2 (A)
/Screen1/SW8: CP22.1, D325.2 (A), D326.2 (A), D327.2 (A), D328.2 (A), D329.2 (A), D330.2 (A), D331.2 (A), D332.2 (A), D333.2 (A), D334.2 (A), D335.2 (A), D336.2 (A), D337.2 (A), D338.2 (A), D339.2 (A), D340.2 (A), D341.2 (A), D342.2 (A)
/Screen1/SW9: CP16.1, D343.2 (A), D344.2 (A), D345.2 (A), D346.2 (A), D347.2 (A), D348.2 (A), D349.2 (A), D350.2 (A), D351.2 (A), D352.2 (A), D353.2 (A), D354.2 (A), D355.2 (A), D356.2 (A), D357.2 (A), D358.2 (A), D359.2 (A), D360.2 (A)
/Screen1/SW10: CP10.1, D361.2 (A), D362.2 (A), D363.2 (A), D364.2 (A), D365.2 (A), D366.2 (A), D367.2 (A), D368.2 (A), D369.2 (A), D370.2 (A), D371.2 (A), D372.2 (A), D373.2 (A), D374.2 (A), D375.2 (A), D376.2 (A), D377.2 (A), D378.2 (A)
/Screen1/SW11: CP4.1, D379.2 (A), D380.2 (A), D381.2 (A), D382.2 (A), D383.2 (A), D384.2 (A), D385.2 (A), D386.2 (A), D387.2 (A), D388.2 (A), D389.2 (A), D390.2 (A), D391.2 (A), D392.2 (A), D393.2 (A), D394.2 (A), D395.2 (A), D396.2 (A)
/Screen2/CS1: CP174.1, D397.1 (K), D415.1 (K), D433.1 (K), D451.1 (K), D469.1 (K), D487.1 (K), D505.1 (K), D523.1 (K), D541.1 (K), D559.1 (K), D577.1 (K)
/Screen2/CS2: CP168.1, D398.1 (K), D416.1 (K), D434.1 (K), D452.1 (K), D470.1 (K), D488.1 (K), D506.1 (K), D524.1 (K), D542.1 (K), D560.1 (K), D578.1 (K)
/Screen2/CS3: CP162.1, D399.1 (K), D417.1 (K), D435.1 (K), D453.1 (K), D471.1 (K), D489.1 (K), D507.1 (K), D525.1 (K), D543.1 (K), D561.1 (K), D579.1 (K)
/Screen2/CS4: CP156.1, D400.1 (K), D418.1 (K), D436.1 (K), D454.1 (K), D472.1 (K), D490.1 (K), D508.1 (K), D526.1 (K), D544.1 (K), D562.1 (K), D580.1 (K)
/Screen2/CS5: CP150.1, D401.1 (K), D419.1 (K), D437.1 (K), D455.1 (K), D473.1 (K), D491.1 (K), D509.1 (K), D527.1 (K), D545.1 (K), D563.1 (K), D581.1 (K)
/Screen2/CS6: CP144.1, D402.1 (K), D420.1 (K), D438.1 (K), D456.1 (K), D474.1 (K), D492.1 (K), D510.1 (K), D528.1 (K), D546.1 (K), D564.1 (K), D582.1 (K)
/Screen2/CS7: CP138.1, D403.1 (K), D421.1 (K), D439.1 (K), D457.1 (K), D475.1 (K), D493.1 (K), D511.1 (K), D529.1 (K), D547.1 (K), D565.1 (K), D583.1 (K)
/Screen2/CS8: CP132.1, D404.1 (K), D422.1 (K), D440.1 (K), D458.1 (K), D476.1 (K), D494.1 (K), D512.1 (K), D530.1 (K), D548.1 (K), D566.1 (K), D584.1 (K)
/Screen2/CS9: CP126.1, D405.1 (K), D423.1 (K), D441.1 (K), D459.1 (K), D477.1 (K), D495.1 (K), D513.1 (K), D531.1 (K), D549.1 (K), D567.1 (K), D585.1 (K)
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

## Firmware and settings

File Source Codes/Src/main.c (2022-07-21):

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
/* Includes ------------------------------------------------------------------*/
#include "main.h"
#include "usb_device.h"

/* USER CODE BEGIN Includes */
#include "nixie.h"

#ifdef superUserMode
	#include <stdio.h>
	#include "usbd_cdc_if.h"
	extern USBD_HandleTypeDef hUsbDeviceFS;

	uint8_t CMD_Buffer[256], CMD_Len = 0;
#endif
/* USER CODE END Includes */

I2C_HandleTypeDef hi2c1;

TIM_HandleTypeDef htim2;
TIM_HandleTypeDef htim3;

/* USER CODE BEGIN PV */
uint8_t NumOfNodes, IDBuffer[10];

uint8_t image_data_nixie5[199] = { 0x01,  //PWM Page address
	0x01, 0x01, 0x01, 0x01, 0x00, 0x00, 0x01, 0x03, 0x07, 0x07, 0x06, 0x08, 0x0a, 0x09, 0x05, 0x02, 0x01, 0x00,
	0x00, 0x00, 0x01, 0x01, 0x01, 0x03, 0x03, 0x05, 0x0c, 0x0e, 0x11, 0x11, 0x0a, 0x07, 0x05, 0x05, 0x01, 0x00,
	0x02, 0x01, 0x01, 0x03, 0x08, 0x0b, 0x09, 0x0c, 0x14, 0x47, 0x87, 0x95, 0x63, 0x23, 0x08, 0x05, 0x02, 0x00,
	0x03, 0x02, 0x03, 0x06, 0x8e, 0x26, 0x0f, 0x14, 0x5c, 0xa1, 0x21, 0x20, 0x56, 0x97, 0x17, 0x07, 0x02, 0x00,
	0x02, 0x02, 0x04, 0x0c, 0xa6, 0x27, 0x0f, 0x1e, 0x95, 0x27, 0x0f, 0x0c, 0x1b, 0x66, 0x56, 0x08, 0x02, 0x00,
	0x03, 0x03, 0x04, 0x08, 0x96, 0x2a, 0x12, 0x2b, 0x7d, 0x16, 0x11, 0x09, 0x11, 0x31, 0x78, 0x0d, 0x03, 0x00,
	0x01, 0x03, 0x08, 0x11, 0x90, 0x3b, 0x15, 0x1c, 0x96, 0x13, 0x09, 0x08, 0x0c, 0x55, 0x63, 0x0e, 0x03, 0x00,
	0x03, 0x01, 0x02, 0x11, 0x85, 0x98, 0x88, 0x74, 0xc4, 0x5d, 0x0d, 0x0a, 0x2a, 0x91, 0x2b, 0x04, 0x01, 0x00,
	0x04, 0x03, 0x02, 0x07, 0x14, 0x1b, 0x23, 0x37, 0x44, 0x33, 0x08, 0x06, 0x5f, 0x33, 0x04, 0x02, 0x01, 0x00,
	0x01, 0x01, 0x01, 0x03, 0x07, 0x0b, 0x08, 0x09, 0x0c, 0x08, 0x05, 0x11, 0x04, 0x03, 0x03, 0x01, 0x00, 0x00,
	0x01, 0x01, 0x01, 0x02, 0x06, 0x05, 0x03, 0x08, 0x08, 0x09, 0x0f, 0x02, 0x02, 0x04, 0x02, 0x02, 0x00, 0x00
};

/* USER CODE END PV */

void SystemClock_Config(void);
static void MX_GPIO_Init(void);
static void MX_I2C1_Init(void);
static void MX_TIM2_Init(void);
static void MX_TIM3_Init(void);
/**
  * @brief  The application entry point.
  * @retval int
  */
int main(void)
{
  /* MCU Configuration--------------------------------------------------------*/

  /* Reset of all peripherals, Initializes the Flash interface and the Systick. */
  HAL_Init();

  /* Configure the system clock */
  SystemClock_Config();

  /* Initialize all configured peripherals */
  MX_GPIO_Init();
  MX_I2C1_Init();
  MX_TIM2_Init();
  MX_TIM3_Init();
  MX_USB_DEVICE_Init();
  /* USER CODE BEGIN 2 */


#ifdef superUserMode
  NixiBusInit(hi2c1, &hUsbDeviceFS);
#else
  NixiBusInit(hi2c1, NULL);
#endif

  HAL_TIM_Base_Start_IT(&htim2);
  /* USER CODE END 2 */

  /* Infinite loop */
  /* USER CODE BEGIN WHILE */
  while (1)
  {
#ifdef superUserMode
	  superUserRunForever(CMD_Buffer, &CMD_Len);
#endif  //superUserMode


		I2C_Buffer[0] = CommandRegisterWriteLock;
		I2C_Buffer[1] = CommandRegisterWriteUnlock;
		HAL_I2C_Master_Transmit(&NixieBus, Nixie_ID_LeftLeft, I2C_Buffer, 2, 1000);
		HAL_I2C_Master_Transmit(&NixieBus, Nixie_ID_LeftRight, I2C_Buffer, 2, 1000);
		HAL_I2C_Master_Transmit(&NixieBus, Nixie_ID_RightLeft, I2C_Buffer, 2, 1000);
		HAL_I2C_Master_Transmit(&NixieBus, Nixie_ID_RightRight, I2C_Buffer, 2, 1000);

		I2C_Buffer[0] = CommandRegister;
		I2C_Buffer[1] = PWMRegister;
		HAL_I2C_Master_Transmit(&NixieBus, Nixie_ID_LeftLeft, I2C_Buffer, 2, 1000);
		HAL_I2C_Master_Transmit(&NixieBus, Nixie_ID_LeftRight, I2C_Buffer, 2, 1000);
		HAL_I2C_Master_Transmit(&NixieBus, Nixie_ID_RightLeft, I2C_Buffer, 2, 1000);
		HAL_I2C_Master_Transmit(&NixieBus, Nixie_ID_RightRight, I2C_Buffer, 2, 1000);

		HAL_I2C_Master_Transmit(&NixieBus, Nixie_ID_LeftLeft, image_data_nixie5, 199, 1000);
		HAL_I2C_Master_Transmit(&NixieBus, Nixie_ID_LeftRight, image_data_nixie5, 199, 1000);
		HAL_I2C_Master_Transmit(&NixieBus, Nixie_ID_RightLeft, image_data_nixie5, 199, 1000);
		HAL_I2C_Master_Transmit(&NixieBus, Nixie_ID_RightRight, image_data_nixie5, 199, 1000);


	  HAL_Delay(1000);

		I2C_Buffer[0] = 0x01;
		for(uint8_t loop = 1; loop < 0xC7 ; loop ++)
		{
			I2C_Buffer[loop] = 0x0;
		}
			HAL_I2C_Master_Transmit(&NixieBus, Nixie_ID_LeftLeft, I2C_Buffer, 199, 1000);
			HAL_I2C_Master_Transmit(&NixieBus, Nixie_ID_LeftRight, I2C_Buffer, 199, 1000);
			HAL_I2C_Master_Transmit(&NixieBus, Nixie_ID_RightLeft, I2C_Buffer, 199, 1000);
			HAL_I2C_Master_Transmit(&NixieBus, Nixie_ID_RightRight, I2C_Buffer, 199, 1000);

		HAL_Delay(100);

//
//		I2C_Buffer[0] = 0x01;
//		for(uint8_t loop = 1; loop < 0xC7 ; loop ++)
//		{
//			I2C_Buffer[loop] = 0x1F;
//		}
//			HAL_I2C_Master_Transmit(&NixieBus, Nixie_ID_LeftLeft, I2C_Buffer, 199, 1000);
//			HAL_I2C_Master_Transmit(&NixieBus, Nixie_ID_LeftRight, I2C_Buffer, 199, 1000);
//			HAL_I2C_Master_Transmit(&NixieBus, Nixie_ID_RightLeft, I2C_Buffer, 199, 1000);
//			HAL_I2C_Master_Transmit(&NixieBus, Nixie_ID_RightRight, I2C_Buffer, 199, 1000);
//
//		HAL_Delay(2000);


		I2C_Buffer[0] = 0x01;
		for(uint8_t loop = 1; loop < 0xC7 ; loop ++)
		{
			I2C_Buffer[loop] = 0x0;
		}
			HAL_I2C_Master_Transmit(&NixieBus, Nixie_ID_LeftLeft, I2C_Buffer, 199, 1000);
			HAL_I2C_Master_Transmit(&NixieBus, Nixie_ID_LeftRight, I2C_Buffer, 199, 1000);
			HAL_I2C_Master_Transmit(&NixieBus, Nixie_ID_RightLeft, I2C_Buffer, 199, 1000);
			HAL_I2C_Master_Transmit(&NixieBus, Nixie_ID_RightRight, I2C_Buffer, 199, 1000);

		HAL_Delay(500);


		for(uint8_t loop = 1; loop < 0xC7 ; loop ++)
		{
			I2C_Buffer[0] = loop;
			I2C_Buffer[1] = 0x1F;
			HAL_I2C_Master_Transmit(&NixieBus, Nixie_ID_LeftLeft, I2C_Buffer, 2, 1000);
			HAL_I2C_Master_Transmit(&NixieBus, Nixie_ID_LeftRight, I2C_Buffer, 2, 1000);
			HAL_I2C_Master_Transmit(&NixieBus, Nixie_ID_RightLeft, I2C_Buffer, 2, 1000);
			HAL_I2C_Master_Transmit(&NixieBus, Nixie_ID_RightRight, I2C_Buffer, 2, 1000);
		HAL_Delay(50);
		}
    /* USER CODE END WHILE */

    /* USER CODE BEGIN 3 */
  }
  /* USER CODE END 3 */
}

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


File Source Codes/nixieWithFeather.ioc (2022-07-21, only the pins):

Mcu.UserName=STM32F405RGTx
PA11.Signal=USB_OTG_FS_DM
PA12.Signal=USB_OTG_FS_DP
PA13.Signal=SYS_JTMS-SWDIO
PA14.Signal=SYS_JTCK-SWCLK
PB6.Signal=I2C1_SCL
PB7.Signal=I2C1_SDA
PC1.GPIO_Label=LD_RED
PC1.Signal=GPIO_Output
PH0-OSC_IN.Signal=RCC_OSC_IN
PH1-OSC_OUT.Signal=RCC_OSC_OUT

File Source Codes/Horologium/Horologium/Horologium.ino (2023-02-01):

#include "HAL_nixiePanel.h"

nixiePanel myNixiePanel = nixiePanel();

void setup() 
{
  myNixiePanel.begin();
  
/*
  myNixiePanel.myGFX.setFont(&FreeSansOblique9pt7b);
  myNixiePanel.myGFX.fillScreen(0);
  myNixiePanel.myGFX.println("E");
  myNixiePanel.updateScreen();
  */
}


void loop() 
{
  float lineX;

  while(1)
  {
    myNixiePanel.myGFX.fillScreen(0);

    myNixiePanel.myGFX.drawGrayscaleBitmap(lineX, 2.0, 36, 16); 

    myNixiePanel.updateScreen();

    lineX = lineX + 0.1;
    if(lineX > 30)
    {
      lineX = 0;
    }

  }

}

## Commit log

2022-05-12 added the LED driver IC
    [controller.kicad_sch, matrix.kicad_sch, nixie.kicad_pcb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]
2022-05-13 added the datasheet of the LED driver
2022-05-19 all the routing is done
    [controller.kicad_sch, matrix.kicad_sch, nixie.kicad_pcb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]
2022-07-21 last commit before migrating to IS31FL3731
    [nixie-B_Cu.gbl, nixie-B_Mask.gbs, nixie-B_Paste.gbp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]
2022-07-21 added IS31FL3731 and, edited its page
    [controller.kicad_sch, matrix.kicad_sch, nixie.kicad_sch]
2022-12-12 last commit before 0805 migration
    [ControlledMatrix.kicad_sch, controller.kicad_sch, matrix.kicad_sch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]
2022-12-13 split the board to two boards: nixie-panel and nixie-CU
    [ControlledMatrix.kicad_sch, controller.kicad_sch, matrix.kicad_sch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]
2022-12-19 routing is done (mostly). Paused routing, waiting for spaceClaim
    [524651071.step, 524651671.step, 533071071.step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]
2022-12-24 the routing and fine touching is done. Ready for production
    [controller.kicad_sch, nixie-panel.kicad_sch, nixiePanelShape.FCStd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]
2022-12-29 submodule issue...
    [524651071.step, 524651671.step, 533071071.step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]
2022-12-30 created two individual enzyme submodules for each circuit project
    [controller.kicad_sch, matrix.kicad_sch]
2023-01-01 created a documentation structure
    [ControlledMatrix.kicad_sch, controller.kicad_sch, matrix.kicad_sch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]
2023-01-02 started to take note about the LED Driver
2023-01-02 added LED driver circuit pictures
2023-01-03 Added some general overview about ESP32-S3
2023-01-03 added ESP32-S3 Adafruit board to the Notes
2023-01-03 ESP32-S3-Mini front view
2023-01-04 added a picture of the Feather board's pinout
2023-01-04 typo on ESP32-S3 document
2023-01-06 found the necessary libs for s3 esp32 on GitHub
2023-01-07 added macOS guide for esp32 repos
2023-01-07 update on esp32 library installation guide
2023-01-07 update on esp32 note, board selector
2023-01-08 board selector picture
2023-01-08 added note about Adafruit drivers
2023-01-16 ESP32-S3 first code trails
2023-01-18 connected all the drivers to a single I2C bus
2023-01-20 working version of 2 individual clk on single I2C
2023-01-23 added an equation to make gamma correction and it works
    [Horologium.ino]
2023-01-27 improved I2C speed. At least 32 times faster now
2023-02-01 cleaned the code of the LED Driver

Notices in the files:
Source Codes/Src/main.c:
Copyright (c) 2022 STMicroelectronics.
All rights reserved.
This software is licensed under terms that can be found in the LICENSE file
